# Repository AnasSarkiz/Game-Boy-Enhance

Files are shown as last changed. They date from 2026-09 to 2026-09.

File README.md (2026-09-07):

# S4 retro game console in tscircuit

The active project is now a **tabletop HDMI console with USB controllers**, using **T113-S4 / T113M4020DC0**. The default `index.circuit.tsx` opens the S4 design.

The connected draft has **103 components**, a **130 × 110 mm four-layer board**, and seven schematic sheets. It includes power, CPU/clocks/reset, storage/recovery, one protected USB controller port and four labelled indicators: **POWER, RUN, ERROR, USB FAULT**. All supplier footprints and courtyards remain unchanged. The green LED's reversed imported symbol labels are corrected against its manufacturer drawing.

**Routing is disabled. HDMI circuitry, power qualification and a tested firmware image remain incomplete. Do not fabricate.** Placement and connection audits pass; no copper-short DRC or hardware validation has been performed. Registry v1.0.3 remains the earlier draft; GitHub contains the newer console conversion.

See [console design and LED behaviour](s4/CONSOLE-REVIEW.md), [blockers](s4/BLOCKERS.md), [sourcing](s4/JLCPCB-PARTS.md), [current BOM](s4/reports/power-core-bom.csv), and [reproduction commands](s4/README.md).

The user-authorized console change replaces onboard game buttons with USB controllers and speaker/headphone/volume circuitry with TV audio. These are documented scope changes, not DNP workarounds. The previous [Nintendo adaptation](README-AGBM-02.md) and [analog audio review](s4/AUDIO-RETENTION-REVIEW.md) remain historical references.

The original [MouseBiteLabs Enhance](https://github.com/MouseBiteLabs/Game-Boy-Enhance) and pinned Trellis Core references retain their license/attribution notices. See [LICENSE.md](LICENSE.md).

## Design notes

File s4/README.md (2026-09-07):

# T113-S4 tabletop HDMI console

The user approved a tabletop console instead of a handheld. The active processor remains **T113M4020DC0 / C41411351**, using the authorized unchanged S3 supplier geometry. Exact S4 electrical/package qualification remains open.

The connected core has **103 components, 54 nets and seven schematic sheets** on a **130 × 110 mm four-layer board**. Power, CPU/clocks/reset, SD boot storage, USB-C power/recovery, one protected USB-A controller port and four status LEDs are present. HDMI video/audio, source-current management, debug access and a tested Linux/emulator image remain required. Routing stays disabled, with minimum vias of 0.45/0.30 mm.

| Indicator | Meaning |
|---|---|
| POWER, green | 3.3 V rail present |
| RUN, green | Firmware-driven Linux heartbeat |
| ERROR, red | Firmware-reported fault/panic when integrated |
| USB FAULT, red | Hardware USB power-switch fault |

See [connection details and sources](CONSOLE-REVIEW.md), [blockers](BLOCKERS.md), [supplier table](JLCPCB-PARTS.md) and [firmware integration fragment](firmware/console-leds.dtsi). None of the LEDs proves full-board health. The firmware fragment is not a bootable or tested image.

## Active checks

From the repository root, using the installed Bun/tsci toolchain:

```sh
bun run prepare:s4:console
bun run generate:s4:core
bun run typecheck
bun run audit:s4:imports
bun run check:s4:netlist
bun run check:s4:placement
bun run build:s4:core
bun run audit:s4:core
bun run audit:s4:console
bun run audit:s4:retention
bun run preview:s4:sheets
bun run check:release
```

The active stage checks pass with zero emitted diagnostics and a minimum courtyard gap of 0.1044 mm. `check:release` intentionally fails because required console circuitry and routed copper are absent. The separate upstream reference audit still reports unresolved source ERC findings; a successful export never means the reference was electrically qualified.

## Reference and history

The [Trellis Core reference](https://github.com/protolux-electronics/trellis_core/tree/db4fe71623c14bcea47d7457d0db4c99d3899124) supplies selected connections and parts; its custom KiCad footprints are not copied. Manufacturer documentation is reviewed separately. Local imports are genuine `tsci import --jlcpcb --use-exact-footprint` outputs, not handwritten footprints or a fabricated package.

The original AGB CPU/SRAM, LCD, cartridge/link interfaces, battery operation and handheld controls/audio are outside the new tabletop product scope. The [240-row historical disposition table](reports/enhance-retention.csv) records this change without DNP entries. `audio.json`, `controls.json`, audio-only scripts and their reports describe the previous handheld adaptation; they are not inputs to the active console generator or current acceptance checks.

Registry v1.0.3 remains the earlier 112-component stage. The current console entrypoint is available on GitHub; a future registry update must revise its explicit package boundary and release gate, then validate the packaged entrypoint.

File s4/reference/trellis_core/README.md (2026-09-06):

# Trellis Core

This repo serves as a minimum hardware design for the Allwinner T113-S4 (part
number sometimes referred to as T113M4020). This is pin-compatible with the
T113-S3, but with 256MB of RAM in-package. Although generally software-agnostic,
this repo is designed to be used with [Nerves](https://nerves-project.org) and
[nerves_system_trellis](https://github.com/protolux-electronics/nerves_system_trellis).

A screenshot of the PCB 3D rendering

> [!NOTE]
> This hardware design has been extracted out of several proven designs that I
> have previously ordered and tested. While the schematic should be sufficient
> to minimally bring up Linux on this board, the routing and layout as is
> available in this repo has not been tested. You will almost certainly need to
> change it for your application. See the suggestions below.

Want to view the schematic and layout in your browser? Paste this repo's URL
into [KiCanvas](https://kicanvas.org/) by
[@theacodes](https://github.com/theacodes).

## Features

- Allwinner T113-S4 processor
- Flash storage - up to 8GB
- USB-C (power and data)

## Getting Started

[KiCad](https://kicad.org) version 9 or later is required to modify these
designs. To get started, clone this repo and open `trellis_core.kicad_pro` (you
may rename all `trellis_core.kicad_*` files first, if desired). The schematic
already includes:

- DC/DC converters for 3.3V and 0.9V
- 24MHz and 32.768kHz crystals for clocks
- Decoupling capacitors, strapping resistors
- SD-compatible flash storage
- Reset and FEL mode buttons
- UART debug console (UART4)

To add your required peripherals, connect the appropriate signals in the
`CPU IO` sheet. You can see the GPIO pin multiplexing capabilities for the chip
on page 30 of the
[T113 datasheet](https://linux-sunxi.org/images/7/73/T113-s3_datasheet_v1.6.pdf)

## Routing Example

The routing shown in the example board was done rather quickly to showcase the
basics of routing a PCB, while also showing best practices. It uses pretty
standard and inexpensive processes - including 0.2mm minimum trace size, 0.3mm
via drill diameter, and 0402 components. Part numbers have been included in the
metadata for each component, and parts were chosen to maximize the use of basic
and preferred components with JLC assembly.

The board uses a standard 4-layer stackup, with the following layers:

| Layer  | Type |
| --- | --- |
| Top | Signal + GND |
| In1 | GND Plane |
| In2 | 3.3V Plane |
| Bottom | Signal + GND |

For the USB trace, 90 Ohm impedance is required. The trace width and spacing was
calculated for the JLC04161H-7628 stackup from JLCPCB, using the
[JLCPCB impedance calculator](https://jlcpcb.com/pcb-impedance-calculator).
Different manufacturers or stackups may require different settings - please
double check before ordering.

Finally, this design only populates components on the top side to reduce
assembly complexity and cost.

### Suggestions

As mentioned above, this exact design has not been ordered and tested
(derivatives have been, though). If you use this as the template for your
project, I suggest making the following changes to the routing:

- Use wider traces and vias for power connections: 0.9V, 1.5V, 1.8V.
- Any capacitor or resistor in the first row of components around the chip
  should stay close to the chip. Do not move them very far away, as they are
  required for the stability of the design
- If using double sided assembly, feel free to place the decoupling capacitors
  on the reverse side. This will simplify some of the routing and fanout of
  signals
- Keep the SDIO signals for the flash chip relatively short. Right now, they are
  between 20mm and 25mm in length. They should be approximately the same
  length - no more than 10mm different. SDIO is a relatively high speed signal
  of about 50MHz in this configuration. Trace length tuning has been used on
  some of the traces to meet this requirement (don't stress too much though -
  50MHz is pretty forgiving)
- Add stitching vias. Currently, the GND planes are not very well connected, as
  I did not place stitching vias. Via on traces for high speed signals should
  have a nearby GND via, and empty space could be filled with a grid via pattern

## License

Copyright 2025 by Protolux Electronics SARL-S

Trellis Core hardware design files are released under the CERN Open Hardware
Licence, Permissive (CERN-OHL-P). See the LICENSE file for the complete legal
text. In summary:

- You are free to use, study, modify, and distribute the design files for any
  purpose, including personal, educational, or commercial.
- You may make and sell products based on this design without any obligation to
  release your own modifications.
- If you do choose to share modified design files, you must:
  - Retain existing copyright and license notices.
  - Include a short note describing your modifications (what was changed and
    when).
  - Provide a copy of the CERN-OHL-P license alongside your files.

This is a permissive open hardware license, and is similar in spirit to MIT or
BSD licenses in software. It encourages reuse, even in commercial contexts,
while preserving proper attribution.

> [!NOTE]
> Some 3D component models and other assets in this repository are provided
> under their original authors’ licenses. Refer to the individual files or their
> directories for details.

Disclaimer: The Trellis Core design is provided "as is", without any warranty or
guarantee of performance. Use, manufacture, or modification of this hardware is
entirely at your own risk.

## Trademark and Logo Use

The Protolux Electronics name and logo are trademarks of Protolux Electronics
SARL-S.

These marks are not licensed under the CERN-OHL-P license. You may not use the
Protolux Electronics logo or trademarks on any modified versions of this
hardware, on derivative products, or in any way that suggests endorsement or
origin from Protolux Electronics, unless you have received prior written
permission.

## Projects Using this Design

Feel free to open a PR to add your project here! These are some existing
projects that are based off of this design:

| Name | Author | Description |
| --- | --- | --- |
| [Wisteria](https://github.com/protolux-electronics/wisteria_hardware) | Protolux Electronics/Gus Workman | Wisteria is the hardware for the 2025 Goatmire e-ink name badge. Read more about it [here](https://protolux.io/projects/goatmire2025) |
| [Trellis Dev Kit](https://github.com/protolux-electronics/trellis_hardware) | Protolux Electronics/Gus Workman | WIP! Check back soon :) |
| [Nerves Getting Started Hardware Kit]() | Protolux Electronics/Gus Workman | WIP! Check back soon :) |
| Your board here | You | Share your design - open a PR! |

## Designed by Protolux Electronics

Need help with your next embedded project? Interested in a customized T113-based
Nerves board? We're Protolux Electronics, a Luxembourg-based consultancy that
provides hardware and embedded software design services, as well as
manufacturing support. We specialize in embedded solutions using Nerves and
Elixir. Check us out at [https://protolux.io](https://protolux.io)

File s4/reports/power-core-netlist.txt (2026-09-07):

$ tsci check netlist s4/power-core.circuit.tsx
Errors: 0
Warnings: 0

Readable Netlist:
COMPONENTS:
 - C1: 10uF capacitor
 - C2: 10pF capacitor
 - C3: 10uF capacitor
 - C4: 10pF capacitor
 - C5: 22uF capacitor
 - C6: 22uF capacitor
 - C7: 10uF capacitor
 - C8: 100nF capacitor
 - R1: 100kΩ resistor
 - R2: 453kΩ resistor
 - R3: 100kΩ resistor
 - R5: 51kΩ resistor
 - R6: 100kΩ resistor
 - R7: 100kΩ resistor
 - U1: TLV62569PDDCR
 - U2: TLV62569PDDCR
 - L1: L1, source_component
 - L2: L2, source_component
 - C9: 2.2uF capacitor
 - C10: 10uF capacitor
 - C11: 100nF capacitor
 - C12: 100nF capacitor
 - C13: 100nF capacitor
 - C14: 100nF capacitor
 - C15: 100nF capacitor
 - C16: 2.2uF capacitor
 - C17: 100nF capacitor
 - C18: 100nF capacitor
 - C19: 100nF capacitor
 - C20: 100nF capacitor
 - C21: 100nF capacitor
 - C22: 10uF capacitor
 - C23: 100nF capacitor
 - C24: 100nF capacitor
 - C25: 100nF capacitor
 - C26: 100nF capacitor
 - C27: 100nF capacitor
 - C28: 2.2uF capacitor
 - C29: 10uF capacitor
 - C30: 100nF capacitor
 - C31: 100nF capacitor
 - C32: 10pF capacitor
 - C33: 10pF capacitor
 - C34: 100nF capacitor
 - C35: 100nF capacitor
 - C36: 18pF capacitor
 - C37: 18pF capacitor
 - C38: 100nF capacitor
 - C39: 100nF capacitor
 - C40: 2.2uF capacitor
 - R10: 240Ω resistor
 - R11: 100kΩ resistor
 - U3: T113M4020DC0
 - SW1: SW1, source_component
 - Y1: Y1, source_component
 - Y2: Y2, source_component
 - R12: 5.1kΩ resistor
 - R13: 5.1kΩ resistor
 - R14: 5.1kΩ resistor
 - R24: 5.1kΩ resistor
 - R25: 5.1kΩ resistor
 - R15: 5.1kΩ resistor
 - R16: 5.1kΩ resistor
 - U4: USBLC6-2SC6
 - F1: F1, source_component
 - J1: J1, source_component
 - C41: 10uF capacitor
 - C42: 100nF capacitor
 - C43: 100nF capacitor
 - C44: 100nF capacitor
 - R17: 51kΩ resistor
 - R18: 51kΩ resistor
 - R19: 51kΩ resistor
 - R20: 51kΩ resistor
 - R21: 51kΩ resistor
 - R22: 5.1kΩ resistor
 - R23: 22Ω resistor
 - U5: ZDSD04GLGEAG
 - U6: SN74AHC1G08DCKR
 - SW2: SW2, source_component
 - R4: 1kΩ resistor
 - D1: D1, source_component
 - LED2: LED2, source_component
 - LED3: LED3, source_component
 - LED4: LED4, source_component
 - Q2: Q2, source_component
 - Q3: Q3, source_component
 - R48: 1kΩ resistor
 - R49: 1kΩ resistor
 - R50: 1kΩ resistor
 - R51: 10kΩ resistor
 - R52: 100kΩ resistor
 - R53: 10kΩ resistor
 - R54: 100kΩ resistor
 - U9: TPS2051BDBVR
 - U10: USBLC6-2SC6
 - J4: J4, source_component
 - R55: 100kΩ resistor
 - R56: 10kΩ resistor
 - C70: 100nF capacitor
 - C71: 10uF capacitor
 - C72: 220uF capacitor
 - C73: 100nF capacitor

NET: VDD_CORE_0V9
  - U3 VDD_SYS2
  - U3 VDD_SYS1
  - U3 VDD_SYS0
  - U3 VDD_CORE1
  - U3 VDD_CORE0
  - R5 pin1
  - L2 pin2 (-)
  - C6 pin1 (+)
  - C5 pin1 (+)
  - C4 pin1 (+)
  - C27 pin1 (+)
  - C26 pin1 (+)
  - C25 pin1 (+)
  - C24 pin1 (+)
  - C23 pin1 (+)
  - C22 pin1 (+)

NET: DDR_1V5
  - U3 VCC_DRAM1
  - U3 VCC_DRAM0
  - U3 LDOB_OUT
  - C31 pin1 (+)
  - C30 pin1 (+)
  - C29 pin1 (+)
  - C28 pin1 (+)

NET: LDOA_1V8
  - R11 pin1
  - U3 HPVCC
  - U3 AVCC
  - U3 VCC_LVDS
  - U3 VDD18_DRAM
  - U3 LDOA_OUT
  - U3 VCC_RTC
  - U3 VCC_PLL
  - U3 VCC_TVIN
  - C35 pin1 (+)
  - C34 pin1 (+)
  - C21 pin1 (+)
  - C20 pin1 (+)
  - C19 pin1 (+)
  - C18 pin1 (+)
  - C17 pin1 (+)
  - C16 pin1 (+)

NET: SYS_3V3
  - R56 pin1
  - LED4 anode (+)
  - LED3 anode (+)
  - LED2 anode (+)
  - U6 VCC
  - U5 VDD
  - U3 VCC_IO
  - U3 VCC_TVOUT
  - U3 VCC_PD
  - U3 VCC_PE
  - U3 LDO_IN
  - U3 VCC_PG
  - R22 pin2
  - R21 pin1
  - R20 pin1
  - R2 pin1
  - R19 pin1
  - R18 pin1
  - R17 pin1
  - R13 pin1
  - R12 pin1
  - L1 pin2 (-)
  - D1 anode (+)
  - C9 pin1 (+)
  - C43 pin1 (+)
  - C42 pin1 (+)
  - C41 pin1 (+)
  - C3 pin1 (+)
  - C2 pin1 (+)
  - C15 pin1 (+)
  - C14 pin1 (+)
  - C13 pin1 (+)
  - C12 pin1 (+)
  - C11 pin1 (+)
  - C10 pin1 (+)

NET: DXIN
  - Y1 pin1
  - U3 DXIN
  - C32 pin1 (+)

NET: DXOUT
  - Y1 pin3
  - U3 DXOUT
  - C33 pin1 (+)

NET: LXIN
  - Y2 pin1 (+)
  - U3 X32KIN
  - C36 pin1 (+)

NET: LXOUT
  - Y2 pin2 (-)
  - U3 X32KOUT
  - C37 pin1 (+)

NET: RESET_N
  - U3 RESET
  - SW1 pin2
  - R11 pin2
  - C40 pin1 (+)

NET: BOARD_ID_1
  - U3 PF6
  - R14 pin1

NET: BOARD_ID_2
  - U3 PE8
  - R24 pin1

NET: BOARD_ID_3
  - U3 PE9
  - R25 pin1

NET: BOOT_SEL0
  - U3 PC4
  - R13 pin2

NET: BOOT_SEL1
  - U3 PC5
  - R12 pin2

NET: SDC0_CLK
  - U6 A
  - U3 PF2

NET: SDC0_CMD
  - U5 CMD
  - U3 PF3
  - R19 pin2

NET: SDC0_D0
  - U5 DAT0
  - U3 PF1
  - R18 pin2

NET: SDC0_D1
  - U5 DAT1
  - U3 PF0
  - R17 pin2

NET: SDC0_D2
  - U5 DAT2
  - U3 PF5
  - R21 pin2

NET: SDC0_D3
  - U5 DAT3
  - U3 PF4
  - R20 pin2

NET: SYS_3V3_PG
  - U2 EN
  - U1 PG
  - R6 pin2
  - C8 pin1 (+)

NET: USB0_CC1
  - R15 pin1
  - J1 A5

NET: USB0_CC2
  - R16 pin1
  - J1 B5

NET: USB0_DM
  - J1 B7
  - J1 A7
  - U4 IO11
  - U4 IO12
  - U3 USB0_DM

NET: USB0_DP
  - J1 A6
  - J1 B6
  - U4 IO21
  - U4 IO22
  - U3 USB0_DP

NET: GND
  - C73 pin2 (-)
  - C72 pin2 (-)
  - C71 pin2 (-)
  - C70 pin2 (-)
  - R55 pin2
  - J4 SH2
  - J4 SH1
  - J4 GND
  - U10 GND
  - U9 GND
  - R54 pin2
  - R52 pin2
  - Q3 pin2
  - Q2 pin2
  - Y1 pin4
  - Y1 pin2
  - U6 GND
  - U5 GND
  - U4 GND
  - U3 FMINL
  - U3 FMINR
  - U3 AGND
  - U3 EPAD
  - U2 GND
  - U1 GND
  - SW2 pin1
  - SW1 pin1
  - R7 pin2
  - R4 pin2
  - R3 pin2
  - R25 pin2
  - R24 pin2
  - R16 pin2
  - R15 pin2
  - R14 pin2
  - R10 pin2
  - J1 B1A12
  - J1 A1B12
  - J1 pin4
  - J1 pin3
  - J1 pin2
  - J1 pin1
  - C9 pin2 (-)
  - C8 pin2 (-)
  - C7 pin2 (-)
  - C6 pin2 (-)
  - C5 pin2 (-)
  - C44 pin2 (-)
  - C43 pin2 (-)
  - C42 pin2 (-)
  - C41 pin2 (-)
  - C40 pin2 (-)
  - C39 pin2 (-)
  - C38 pin2 (-)
  - C37 pin2 (-)
  - C36 pin2 (-)
  - C35 pin2 (-)
  - C34 pin2 (-)
  - C33 pin2 (-)
  - C32 pin2 (-)
  - C31 pin2 (-)
  - C30 pin2 (-)
  - C3 pin2 (-)
  - C29 pin2 (-)
  - C28 pin2 (-)
  - C27 pin2 (-)
  - C26 pin2 (-)
  - C25 pin2 (-)
  - C24 pin2 (-)
  - C23 pin2 (-)
  - C22 pin2 (-)
  - C21 pin2 (-)
  - C20 pin2 (-)
  - C19 pin2 (-)
  - C18 pin2 (-)
  - C17 pin2 (-)
  - C16 pin2 (-)
  - C15 pin2 (-)
  - C14 pin2 (-)
  - C13 pin2 (-)
  - C12 pin2 (-)
  - C11 pin2 (-)
  - C10 pin2 (-)
  - C1 pin2 (-)

NET: FEL_CLOCK_ENABLE
  - U6 B
  - SW2 pin2
  - R22 pin1
  - C44 pin1 (+)

NET: Net__D1_K_
  - R4 pin1
  - D1 cathode (-)

NET: SDC0_CLK_BUFFERED
  - U6 Y
  - R23 pin1

NET: BUCK_3V3_EN
  - U1 EN
  - R1 pin2

NET: BUCK_3V3_FB
  - U1 FB
  - R3 pin1
  - R2 pin2
  - C2 pin2 (-)

NET: BUCK_3V3_SW
  - U1 SW
  - L1 pin1 (+)

NET: BUCK_CORE_FB
  - U2 FB
  - R7 pin1
  - R5 pin2
  - C4 pin2 (-)

NET: BUCK_CORE_SW
  - U2 SW
  - L2 pin1 (+)

NET: DDR_ZQ
  - U3 DZQ
  - R10 pin1

NET: Net__U3F_VRA1_
  - U3 VRA1
  - C39 pin1 (+)

NET: Net__U3F_VRA2_
  - U3 VRA2
  - C38 pin1 (+)

NET: USB_C_VBUS_5V
  - U4 VBUS
  - J1 B4A9
  - J1 A4B9
  - F1 pin1

NET: SDC0_CLK_STORAGE
  - U5 CLK
  - R23 pin2

NET: INPUT_5V
  - C71 pin1 (+)
  - C70 pin1 (+)
  - U9 IN
  - U2 VIN
  - U1 VIN
  - R6 pin1
  - R1 pin1
  - F1 pin2
  - C7 pin1 (+)
  - C1 pin1 (+)

NET: LED_RUN
  - R51 pin1
  - U3 PE0

NET: LED_RUN_BASE
  - R52 pin1
  - Q2 pin1
  - R51 pin2

NET: LED_RUN_CATHODE
  - R48 pin1
  - LED2 cathode (-)

NET: LED_RUN_SINK
  - Q2 pin3
  - R48 pin2

NET: LED_ERROR
  - R53 pin1
  - U3 PE1

NET: LED_ERROR_BASE
  - R54 pin1
  - Q3 pin1
  - R53 pin2

NET: LED_ERROR_CATHODE
  - R49 pin1
  - LED3 cathode (-)

NET: LED_ERROR_SINK
  - Q3 pin3
  - R49 pin2

NET: LED_USB_FAULT_CATHODE
  - R50 pin1
  - LED4 cathode (-)

NET: USB_HOST_FAULT_N
  - R50 pin2
  - R56 pin2
  - U3 PG9
  - U9 N_OC

NET: USB_HOST_ENABLE
  - R55 pin1
  - U3 PG10
  - U9 EN

NET: USB_HOST_5V
  - C73 pin1 (+)
  - C72 pin1 (+)
  - U10 VBUS
  - J4 VCC
  - U9 OUT

NET: USB1_DM
  - J4 D_NEG
  - U10 IO11
  - U10 IO12
  - U3 USB1_DM

NET: USB1_DP
  - J4 D_POS
  - U10 IO21
  - U10 IO22
  - U3 USB1_DP

COMPONENT_PINS:
C1 (10uF undefined)
- pin1(pos): NETS(INPUT_5V)
- pin2(neg): NETS(GND)

C2 (10pF undefined)
- pin1(pos): NETS(SYS_3V3)
- pin2(neg): NETS(BUCK_3V3_FB)

C3 (10uF undefined)
- pin1(pos): NETS(SYS_3V3)
- pin2(neg): NETS(GND)

C4 (10pF undefined)
- pin1(pos): NETS(VDD_CORE_0V9)
- pin2(neg): NETS(BUCK_CORE_FB)

C5 (22uF undefined)
- pin1(pos): NETS(VDD_CORE_0V9)
- pin2(neg): NETS(GND)

C6 (22uF undefined)
- pin1(pos): NETS(VDD_CORE_0V9)
- pin2(neg): NETS(GND)

C7 (10uF undefined)
- pin1(pos): NETS(INPUT_5V)
- pin2(neg): NETS(GND)

C8 (100nF undefined)
- pin1(pos): NETS(SYS_3V3_PG)
- pin2(neg): NETS(GND)

R1 (100kΩ undefined)
- pin1(anode, pos, left): NETS(INPUT_5V)
- pin2(cathode, neg, right): NETS(BUCK_3V3_EN)

R2 (453kΩ undefined)
- pin1(anode, pos, left): NETS(SYS_3V3)
- pin2(cathode, neg, right): NETS(BUCK_3V3_FB)

R3 (100kΩ undefined)
- pin1(anode, pos, left): NETS(BUCK_3V3_FB)
- pin2(cathode, neg, right): NETS(GND)

R5 (51kΩ undefined)
- pin1(anode, pos, left): NETS(VDD_CORE_0V9)
- pin2(cathode, neg, right): NETS(BUCK_CORE_FB)

R6 (100kΩ undefined)
- pin1(anode, pos, left): NETS(INPUT_5V)
- pin2(cathode, neg, right): NETS(SYS_3V3_PG)

R7 (100kΩ undefined)
- pin1(anode, pos, left): NETS(BUCK_CORE_FB)
- pin2(cathode, neg, right): NETS(GND)

U1 (TLV62569PDDCR)
- pin1(EN): NETS(BUCK_3V3_EN)
- pin2(GND): NETS(GND)
- pin3(SW): NETS(BUCK_3V3_SW)
- pin4(VIN): NETS(INPUT_5V)
- pin5(PG): NETS(SYS_3V3_PG)
- pin6(FB): NETS(BUCK_3V3_FB)

U2 (TLV62569PDDCR)
- pin1(EN): NETS(SYS_3V3_PG)
- pin2(GND): NETS(GND)
- pin3(SW): NETS(BUCK_CORE_SW)
- pin4(VIN): NETS(INPUT_5V)
- pin5(PG): NOT_CONNECTED
- pin6(FB): NETS(BUCK_CORE_FB)

L1 (XRIM252012S2R2MBCA)
- pin1(anode, pos, left): NETS(BUCK_3V3_SW)
- pin2(cathode, neg, right): NETS(SYS_3V3)

L2 (XRIM252012S2R2MBCA)
- pin1(anode, pos, left): NETS(BUCK_CORE_SW)
- pin2(cathode, neg, right): NETS(VDD_CORE_0V9)

C9 (2.2uF undefined)
- pin1(pos): NETS(SYS_3V3)
- pin2(neg): NETS(GND)

C10 (10uF undefined)
- pin1(pos): NETS(SYS_3V3)
- pin2(neg): NETS(GND)

C11 (100nF undefined)
- pin1(pos): NETS(SYS_3V3)
- pin2(neg): NETS(GND)

C12 (100nF undefined)
- pin1(pos): NETS(SYS_3V3)
- pin2(neg): NETS(GND)

C13 (100nF undefined)
- pin1(pos): NETS(SYS_3V3)
- pin2(neg): NETS(GND)

C14 (100nF undefined)
- pin1(pos): NETS(SYS_3V3)
- pin2(neg): NETS(GND)

C15 (100nF undefined)
- pin1(pos): NETS(SYS_3V3)
- pin2(neg): NETS(GND)

C16 (2.2uF undefined)
- pin1(pos): NETS(LDOA_1V8)
- pin2(neg): NETS(GND)

C17 (100nF undefined)
- pin1(pos): NETS(LDOA_1V8)
- pin2(neg): NETS(GND)

C18 (100nF undefined)
- pin1(pos): NETS(LDOA_1V8)
- pin2(neg): NETS(GND)

C19 (100nF undefined)
- pin1(pos): NETS(LDOA_1V8)
- pin2(neg): NETS(GND)

C20 (100nF undefined)
- pin1(pos): NETS(LDOA_1V8)
- pin2(neg): NETS(GND)

C21 (100nF undefined)
- pin1(pos): NETS(LDOA_1V8)
- pin2(neg): NETS(GND)

C22 (10uF undefined)
- pin1(pos): NETS(VDD_CORE_0V9)
- pin2(neg): NETS(GND)

C23 (100nF undefined)
- pin1(pos): NETS(VDD_CORE_0V9)
- pin2(neg): NETS(GND)

C24 (100nF undefined)
- pin1(pos): NETS(VDD_CORE_0V9)
- pin2(neg): NETS(GND)

C25 (100nF undefined)
- pin1(pos): NETS(VDD_CORE_0V9)
- pin2(neg): NETS(GND)

C26 (100nF undefined)
- pin1(pos): NETS(VDD_CORE_0V9)
- pin2(neg): NETS(GND)

C27 (100nF undefined)
- pin1(pos): NETS(VDD_CORE_0V9)
- pin2(neg): NETS(GND)

C28 (2.2uF undefined)
- pin1(pos): NETS(DDR_1V5)
- pin2(neg): NETS(GND)

C29 (10uF undefined)
- pin1(pos): NETS(DDR_1V5)
- pin2(neg): NETS(GND)

C30 (100nF undefined)
- pin1(pos): NETS(DDR_1V5)
- pin2(neg): NETS(GND)

C31 (100nF undefined)
- pin1(pos): NETS(DDR_1V5)
- pin2(neg): NETS(GND)

C32 (10pF undefined)
- pin1(pos): NETS(DXIN)
- pin2(neg): NETS(GND)

C33 (10pF undefined)
- pin1(pos): NETS(DXOUT)
- pin2(neg): NETS(GND)

C34 (100nF undefined)
- pin1(pos): NETS(LDOA_1V8)
- pin2(neg): NETS(GND)

C35 (100nF undefined)
- pin1(pos): NETS(LDOA_1V8)
- pin2(neg): NETS(GND)

C36 (18pF undefined)
- pin1(pos): NETS(LXIN)
- pin2(neg): NETS(GND)

C37 (18pF undefined)
- pin1(pos): NETS(LXOUT)
- pin2(neg): NETS(GND)

C38 (100nF undefined)
- pin1(pos): NETS(Net__U3F_VRA2_)
- pin2(neg): NETS(GND)

C39 (100nF undefined)
- pin1(pos): NETS(Net__U3F_VRA1_)
- pin2(neg): NETS(GND)

C40 (2.2uF undefined)
- pin1(pos): NETS(RESET_N)
- pin2(neg): NETS(GND)

R10 (240Ω undefined)
- pin1(anode, pos, left): NETS(DDR_ZQ)
- pin2(cathode, neg, right): NETS(GND)

R11 (100kΩ undefined)
- pin1(anode, pos, left): NETS(LDOA_1V8)
- pin2(cathode, neg, right): NETS(RESET_N)

U3 (T113M4020DC0)
- pin1(PG6): NOT_CONNECTED
- pin2(PG7): NOT_CONNECTED
- pin3(PG8): NOT_CONNECTED
- pin4(PG9): NETS(USB_HOST_FAULT_N)
- pin5(PG10): NETS(USB_HOST_ENABLE)
- pin6(PG11): NOT_CONNECTED
- pin7(PF0): NETS(SDC0_D1)
- pin8(PF1): NETS(SDC0_D0)
- pin9(PF2): NETS(SDC0_CLK)
- pin10(PF3): NETS(SDC0_CMD)
- pin11(PF4): NETS(SDC0_D3)
- pin12(PF5): NETS(SDC0_D2)
- pin13(PF6): NETS(BOARD_ID_1)
- pin14(PC7): NOT_CONNECTED
- pin15(PC6): NOT_CONNECTED
- pin16(PC5): NETS(BOOT_SEL1)
- pin17(PC4): NETS(BOOT_SEL0)
- pin18(PC3): NOT_CONNECTED
- pin19(PC2): NOT_CONNECTED
- pin20(VCC_PLL): NETS(LDOA_1V8)
- pin21(REFCLK_OUT): NOT_CONNECTED
- pin22(DXOUT): NETS(DXOUT)
- pin23(DXIN): NETS(DXIN)
- pin24(X32KOUT): NETS(LXOUT)
- pin25(X32KIN): NETS(LXIN)
- pin26(VCC_RTC): NETS(LDOA_1V8)
- pin27(RESET): NETS(RESET_N)
- pin28(LDOA_OUT): NETS(LDOA_1V8)
- pin29(LDO_IN): NETS(SYS_3V3)
- pin30(LDOB_OUT): NETS(DDR_1V5)
- pin31(PE13): NOT_CONNECTED
- pin32(PE12): NOT_CONNECTED
- pin33(PE3): NOT_CONNECTED
- pin34(VCC_PE): NETS(SYS_3V3)
- pin35(PE2): NOT_CONNECTED
- pin36(PE11): NOT_CONNECTED
- pin37(PE10): NOT_CONNECTED
- pin38(PE9): NETS(BOARD_ID_3)
- pin39(PE8): NETS(BOARD_ID_2)
- pin40(PE7): NOT_CONNECTED
- pin41(PE6): NOT_CONNECTED
- pin42(PE5): NOT_CONNECTED
- pin43(PE4): NOT_CONNECTED
- pin44(PE0): NETS(LED_RUN)
- pin45(PE1): NETS(LED_ERROR)
- pin46(VDD_SYS0): NETS(VDD_CORE_0V9)
- pin47(DZQ): NETS(DDR_ZQ)
- pin48(VCC_DRAM0): NETS(DDR_1V5)
- pin49(VCC_DRAM1): NETS(DDR_1V5)
- pin50(VDD18_DRAM): NETS(LDOA_1V8)
- pin51(VDD_SYS1): NETS(VDD_CORE_0V9)
- pin52(PD22): NOT_CONNECTED
- pin53(PD21): NOT_CONNECTED
- pin54(PD20): NOT_CONNECTED
- pin55(PD0): NOT_CONNECTED
- pin56(PD1): NOT_CONNECTED
- pin57(PD2): NOT_CONNECTED
- pin58(PD3): NOT_CONNECTED
- pin59(PD4): NOT_CONNECTED
- pin60(PD5): NOT_CONNECTED
- pin61(PD6): NOT_CONNECTED
- pin62(PD7): NOT_CONNECTED
- pin63(PD8): NOT_CONNECTED
- pin64(PD9): NOT_CONNECTED
- pin65(VCC_LVDS): NETS(LDOA_1V8)
- pin66(VCC_PD): NETS(SYS_3V3)
- pin67(PD10): NOT_CONNECTED
- pin68(PD11): NOT_CONNECTED
- pin69(PD13): NOT_CONNECTED
- pin70(PD12): NOT_CONNECTED
- pin71(PD14): NOT_CONNECTED
- pin72(PD15): NOT_CONNECTED
- pin73(PD16): NOT_CONNECTED
- pin74(PD17): NOT_CONNECTED
- pin75(PD18): NOT_CONNECTED
- pin76(PD19): NOT_CONNECTED
- pin77(VCC_TVOUT): NETS(SYS_3V3)
- pin78(TVOUT0): NOT_CONNECTED
- pin79(PB7): NOT_CONNECTED
- pin80(PB6): NOT_CONNECTED
- pin81(VDD_SYS2): NETS(VDD_CORE_0V9)
- pin82(PB5): NOT_CONNECTED
- pin83(VCC_IO): NETS(SYS_3V3)
- pin84(PB4): NOT_CONNECTED
- pin85(PB3): NOT_CONNECTED
- pin86(PB2): NOT_CONNECTED
- pin87(MICIN3P): NOT_CONNECTED
- pin88(MICIN3N): NOT_CONNECTED
- pin89(AVCC): NETS(LDOA_1V8)
- pin90(VRA2): NETS(Net__U3F_VRA2_)
- pin91(AGND): NETS(GND)
- pin92(VRA1): NETS(Net__U3F_VRA1_)
- pin93(FMINR): NETS(GND)
- pin94(FMINL): NETS(GND)
- pin95(LINEINR): NOT_CONNECTED
- pin96(LINEINL): NOT_CONNECTED
- pin97(HPVCC): NETS(LDOA_1V8)
- pin98(HPOUTR): NOT_CONNECTED
- pin99(HPOUTL): NOT_CONNECTED
- pin100(HPOUTFB): NOT_CONNECTED
- pin101(GPADC0): NOT_CONNECTED
- pin102(TP_X1): NOT_CONNECTED
- pin103(TP_X2): NOT_CONNECTED
- pin104(TP_Y1): NOT_CONNECTED
- pin105(TP_Y2): NOT_CONNECTED
- pin106(NC0): NOT_CONNECTED
- pin107(VCC_TVIN): NETS(LDOA_1V8)
- pin108(TVIN0): NOT_CONNECTED
- pin109(TVIN1): NOT_CONNECTED
- pin110(TVIN_VRP): NOT_CONNECTED
- pin111(TVIN_VRN): NOT_CONNECTED
- pin112(USB1_DP): NETS(USB1_DP)
- pin113(USB1_DM): NETS(USB1_DM)
- pin114(USB0_DM): NETS(USB0_DM)
- pin115(USB0_DP): NETS(USB0_DP)
- pin116(VDD_CORE0): NETS(VDD_CORE_0V9)
- pin117(VDD_CORE1): NETS(VDD_CORE_0V9)
- pin118(PG1): NOT_CONNECTED
- pin119(PG2): NOT_CONNECTED
- pin120(PG0): NOT_CONNECTED
- pin121(PG3): NOT_CONNECTED
- pin122(PG5): NOT_CONNECTED
- pin123(PG4): NOT_CONNECTED
- pin124(PG12): NOT_CONNECTED
- pin125(PG13): NOT_CONNECTED
- pin126(PG14): NOT_CONNECTED
- pin127(PG15): NOT_CONNECTED
- pin128(VCC_PG): NETS(SYS_3V3)
- pin129(EPAD): NETS(GND)

SW1 (TSA010A2026B)
- pin1: NETS(GND)
- pin2: NETS(RESET_N)

Y1 (CM4024M00008001)
- pin1(left1, X1): NETS(DXIN)
- pin2(gnd2, top1, gnd1): NETS(GND)
- pin3(right1, X2): NETS(DXOUT)
- pin4(gnd1, bottom1, gnd2): NETS(GND)

Y2 (Q13FC13500004)
- pin1(pos, left, X1): NETS(LXIN)
- pin2(neg, right, X2): NETS(LXOUT)

R12 (5.1kΩ undefined)
- pin1(anode, pos, left): NETS(SYS_3V3)
- pin2(cathode, neg, right): NETS(BOOT_SEL1)

R13 (5.1kΩ undefined)
- pin1(anode, pos, left): NETS(SYS_3V3)
- pin2(cathode, neg, right): NETS(BOOT_SEL0)

R14 (5.1kΩ undefined)
- pin1(anode, pos, left): NETS(BOARD_ID_1)
- pin2(cathode, neg, right): NETS(GND)

R24 (5.1kΩ undefined)
- pin1(anode, pos, left): NETS(BOARD_ID_2)
- pin2(cathode, neg, right): NETS(GND)

R25 (5.1kΩ undefined)
- pin1(anode, pos, left): NETS(BOARD_ID_3)
- pin2(cathode, neg, right): NETS(GND)

R15 (5.1kΩ undefined)
- pin1(anode, pos, left): NETS(USB0_CC1)
- pin2(cathode, neg, right): NETS(GND)

R16 (5.1kΩ undefined)
- pin1(anode, pos, left): NETS(USB0_CC2)
- pin2(cathode, neg, right): NETS(GND)

U4 (USBLC6-2SC6)
- pin1(IO11): NETS(USB0_DM)
- pin2(GND): NETS(GND)
- pin3(IO21): NETS(USB0_DP)
- pin4(IO22): NETS(USB0_DP)
- pin5(VBUS): NETS(USB_C_VBUS_5V)
- pin6(IO12): NETS(USB0_DM)

F1 (JK-nSMD100-16)
- pin1: NETS(USB_C_VBUS_5V)
- pin2: NETS(INPUT_5V)

J1 (HX TYPE-C 16P L8.35)
- pin1: NETS(GND)
- pin2: NETS(GND)
- pin3: NETS(GND)
- pin4: NETS(GND)
- pin5(A1B12, GND1): NETS(GND)
- pin6(A4B9, VBUS1): NETS(USB_C_VBUS_5V)
- pin7(B1A12, GND2): NETS(GND)
- pin8(B4A9, VBUS2): NETS(USB_C_VBUS_5V)
- pin9(B5, CC2): NETS(USB0_CC2)
- pin10(A8, SBU1): NOT_CONNECTED
- pin11(B6, DP2): NETS(USB0_DP)
- pin12(A7, DN1): NETS(USB0_DM)
- pin13(A6, DP1): NETS(USB0_DP)
- pin14(B7, DN2): NETS(USB0_DM)
- pin15(A5, CC1): NETS(USB0_CC1)
- pin16(B8, SBU2): NOT_CONNECTED

C41 (10uF undefined)
- pin1(pos): NETS(SYS_3V3)
- pin2(neg): NETS(GND)

C42 (100nF undefined)
- pin1(pos): NETS(SYS_3V3)
- pin2(neg): NETS(GND)

C43 (100nF undefined)
- pin1(pos): NETS(SYS_3V3)
- pin2(neg): NETS(GND)

C44 (100nF undefined)
- pin1(pos): NETS(FEL_CLOCK_ENABLE)
- pin2(neg): NETS(GND)

R17 (51kΩ undefined)
- pin1(anode, pos, left): NETS(SYS_3V3)
- pin2(cathode, neg, right): NETS(SDC0_D1)

R18 (51kΩ undefined)
- pin1(anode, pos, left): NETS(SYS_3V3)
- pin2(cathode, neg, right): NETS(SDC0_D0)

R19 (51kΩ undefined)
- pin1(anode, pos, left): NETS(SYS_3V3)
- pin2(cathode, neg, right): NETS(SDC0_CMD)

R20 (51kΩ undefined)
- pin1(anode, pos, left): NETS(SYS_3V3)
- pin2(cathode, neg, right): NETS(SDC0_D3)

R21 (51kΩ undefined)
- pin1(anode, pos, left): NETS(SYS_3V3)
- pin2(cathode, neg, right): NETS(SDC0_D2)

R22 (5.1kΩ undefined)
- pin1(anode, pos, left): NETS(FEL_CLOCK_ENABLE)
- pin2(cathode, neg, right): NETS(SYS_3V3)

R23 (22Ω undefined)
- pin1(anode, pos, left): NETS(SDC0_CLK_BUFFERED)
- pin2(cathode, neg, right): NETS(SDC0_CLK_STORAGE)

U5 (ZDSD04GLGEAG)
- pin1(DAT2): NETS(SDC0_D2)
- pin2(DAT3): NETS(SDC0_D3)
- pin3(CLK): NETS(SDC0_CLK_STORAGE)
- pin4(GND): NETS(GND)
- pin5(CMD): NETS(SDC0_CMD)
- pin6(DAT0): NETS(SDC0_D0)
- pin7(DAT1): NETS(SDC0_D1)
- pin8(VDD): NETS(SYS_3V3)

U6 (SN74AHC1G08DCKR)
- pin1(A): NETS(SDC0_CLK)
- pin2(B): NETS(FEL_CLOCK_ENABLE)
- pin3(GND): NETS(GND)
- pin4(Y): NETS(SDC0_CLK_BUFFERED)
- pin5(VCC): NETS(SYS_3V3)

SW2 (TSA010A2026B)
- pin1: NETS(GND)
- pin2: NETS(FEL_CLOCK_ENABLE)

R4 (1kΩ undefined)
- pin1(anode, pos, left): NETS(Net__D1_K_)
- pin2(cathode, neg, right): NETS(GND)

D1 (19-21SYGC/S530-E2/4T)
- pin1(anode, pos): NETS(SYS_3V3)
- pin2(cathode, neg): NETS(Net__D1_K_)

LED2 (19-21SYGC/S530-E2/4T)
- pin1(anode, pos): NETS(SYS_3V3)
- pin2(cathode, neg): NETS(LED_RUN_CATHODE)

LED3 (19-217/R6C-AL1M2VY/6T)
- pin1(anode, pos): NETS(SYS_3V3)
- pin2(cathode, neg): NETS(LED_ERROR_CATHODE)

LED4 (19-217/R6C-AL1M2VY/6T)
- pin1(anode, pos): NETS(SYS_3V3)
- pin2(cathode, neg): NETS(LED_USB_FAULT_CATHODE)

Q2 (MMBT3904LT1G)
- pin1: NETS(LED_RUN_BASE)
- pin2: NETS(GND)
- pin3: NETS(LED_RUN_SINK)

Q3 (MMBT3904LT1G)
- pin1: NETS(LED_ERROR_BASE)
- pin2: NETS(GND)
- pin3: NETS(LED_ERROR_SINK)

R48 (1kΩ undefined)
- pin1(anode, pos, left): NETS(LED_RUN_CATHODE)
- pin2(cathode, neg, right): NETS(LED_RUN_SINK)

R49 (1kΩ undefined)
- pin1(anode, pos, left): NETS(LED_ERROR_CATHODE)
- pin2(cathode, neg, right): NETS(LED_ERROR_SINK)

R50 (1kΩ undefined)
- pin1(anode, pos, left): NETS(LED_USB_FAULT_CATHODE)
- pin2(cathode, neg, right): NETS(USB_HOST_FAULT_N)

R51 (10kΩ undefined)
- pin1(anode, pos, left): NETS(LED_RUN)
- pin2(cathode, neg, right): NETS(LED_RUN_BASE)

R52 (100kΩ undefined)
- pin1(anode, pos, left): NETS(LED_RUN_BASE)
- pin2(cathode, neg, right): NETS(GND)

R53 (10kΩ undefined)
- pin1(anode, pos, left): NETS(LED_ERROR)
- pin2(cathode, neg, right): NETS(LED_ERROR_BASE)

R54 (100kΩ undefined)
- pin1(anode, pos, left): NETS(LED_ERROR_BASE)
- pin2(cathode, neg, right): NETS(GND)

U9 (TPS2051BDBVR)
- pin1(OUT): NETS(USB_HOST_5V)
- pin2(GND): NETS(GND)
- pin3(N_OC): NETS(USB_HOST_FAULT_N)
- pin4(EN): NETS(USB_HOST_ENABLE)
- pin5(IN): NETS(INPUT_5V)

U10 (USBLC6-2SC6)
- pin1(IO11): NETS(USB1_DM)
- pin2(GND): NETS(GND)
- pin3(IO21): NETS(USB1_DP)
- pin4(IO22): NETS(USB1_DP)
- pin5(VBUS): NETS(USB_HOST_5V)
- pin6(IO12): NETS(USB1_DM)

J4 (902-131A1011D10100)
- pin1(VCC): NETS(USB_HOST_5V)
- pin2(D_NEG): NETS(USB1_DM)
- pin3(D_POS): NETS(USB1_DP)
- pin4(GND): NETS(GND)
- pin5(SH1): NETS(GND)
- pin6(SH2): NETS(GND)

R55 (100kΩ undefined)
- pin1(anode, pos, left): NETS(USB_HOST_ENABLE)
- pin2(cathode, neg, right): NETS(GND)

R56 (10kΩ undefined)
- pin1(anode, pos, left): NETS(SYS_3V3)
- pin2(cathode, neg, right): NETS(USB_HOST_FAULT_N)

C70 (100nF undefined)
- pin1(pos): NETS(INPUT_5V)
- pin2(neg): NETS(GND)

C71 (10uF undefined)
- pin1(pos): NETS(INPUT_5V)
- pin2(neg): NETS(GND)

C72 (220uF undefined)
- pin1(pos): NETS(USB_HOST_5V)
- pin2(neg): NETS(GND)

C73 (100nF undefined)
- pin1(pos): NETS(USB_HOST_5V)
- pin2(neg): NETS(GND)

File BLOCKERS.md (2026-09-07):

# Blockers and deviations

## Active tabletop console

The user approved an HDMI console with USB controllers. The active 103-component core adds POWER/RUN/ERROR/USB FAULT indicators and a protected host port; its placement/connection checks pass. HDMI, input-power qualification, S4 documentation, firmware, routing and prototype validation remain unfinished. See [current blockers](s4/BLOCKERS.md), [console review](s4/CONSOLE-REVIEW.md), and [parts table](s4/JLCPCB-PARTS.md).

The following notes describe the historical `agbm-02.circuit.tsx` design.

**Placement-stage work in progress, 2026-09-05. Routing is disabled. Do not fabricate this revision.**

## Sourcing

The [JLCPCB blocker table](JLCPCB-BLOCKERS.md) distinguishes missing exact matches, available alternatives, and catalog import failures.

The [assembly requirements](docs/ASSEMBLY-REQUIREMENTS.md) require every intended function to remain populated and operational. No DNP workaround is permitted. The unresolved CPU/ports, unqualified screen assembly and ineffective legacy JP3 are completion blockers even though no component is marked DNP.

1. **U1 Nintendo AGB CPU:** no verified JLCPCB listing for the original processor. A different TI MCU would not run this hardware as wired. The user's requirements to retain this CPU, import it from JLCPCB and avoid custom footprints cannot all be satisfied without a real catalog listing. All 128 real schematic pins remain; the PCB footprint is unresolved.
2. **P1 cartridge and P4 link connectors:** no verified compatible JLCPCB matches. Their signals and contacts remain in the schematic with unresolved PCB geometry. Generic connectors are not silently substituted.
3. **Requested `@tscircuit/jlcpcb` npm module:** npm returned 404. The available official workflow is `tsci import --jlcpcb --use-exact-footprint`. Genuine generated imports with supplier part numbers and courtyards are used. No fake package or custom component footprint is supplied.

## Electrical and mechanical deviations

Detailed physical pin assignments and manufacturer links are in [PIN-MAPPING.md](docs/PIN-MAPPING.md); electrical checks and unresolved operating limits are in [DATASHEET-AUDIT.md](docs/DATASHEET-AUDIT.md).

| Block | Change from the reference | Remaining qualification |
|---|---|---|
| U2 SRAM | C466866 CY62146EV30LL-45ZSXI; 256 K × 16, 44-pin TSOP, remapped to the original 128 K × 16 bus. JP2 is populated 0 Ω to ground A17. | CPU timing, 200 µs SRAM startup access restriction, loading and compatibility. Original optional BYTE mode is unavailable; JP3 remains an unused legacy header. |
| U4/U8 LDOs | TI TPS74525PQWDRVRQ1 C2865628 replaces NCV8164ASN250T1G; explicit EN/PG/IN/OUT/thermal-pad remap. | PG timing, current limit, output discharge, output noise and current budget differ. |
| U7 audio filters | TI TLV9064IPWR C779410 replaces TLV9364, whose 4.5 V minimum exceeds the reference's 2.5 V VAUD. Same 14-pin quad layout. | Filter response, stability, noise and output loading. |
| U14 timer | MIC1557YM5-TR C144169 follows the upstream BOM instead of the MIC1553 symbol value. | Blink frequency/thresholds; no qualified TI substitution. |
| U9 buffer | Actual noninverting SN74LVC2G34DBVR selected. | The upstream G14 datasheet link describes a different, inverting part. |
| SW1 power | CSS-1210TB C2921710, two-position OFF/ON; correct physical common is pin 3. | Original middle position and nonexistent shield-pad node are omitted. New mechanical actuation differs. |
| SW4/SW5/SW6 | Eight individual Alps SKRRABE010 C125046 switches replace three composite symbols and membrane/contact artwork. | Tactile behavior replaces conductive-pad options; manufacturer underside copper keepouts still need implementation before routing. |
| SW2/SW3 | Exact TE 1825027-5 C86476 is now imported. | Supplier land/hole dimensions and actuation clearance need physical assembly review. Earlier -8 substitution is superseded. |
| VR1/VR2 | JLCPCB trimmer and exact Alps dual volume part use supplier packages; VR2 requires pin remapping. | Wheel/gang continuity and mechanical access need sample confirmation. |
| BT1/SP1 | JLCPCB JST PH two-pin connectors for an external AA holder and speaker. | Original battery/speaker mounting contacts replaced by cables. Speaker remains floating BTL. |
| JP1/JP3/NT1 | Two-pin headers replace solder jumpers; NT1 is a populated 0 Ω joining GND/AGND. | Header/shunt configuration and nonzero net-tie impedance; JP3 does not control the selected SRAM. |
| X1 clock | 4.194304 MHz C718663, larger HC-49S-SMD, 20 pF load. Original 27 pF/33 pF capacitors retained. | CPU oscillator drive, effective load and startup margin are not verified. |
| F1 protection | 1206 fast 2 A 0466002.NRHF C3105 replaces the unimportable original 0805 fuse. | Clearing curve/I²t coordination is not established. |
| Fixed passives/test points | All fixed resistor/capacitor values retained through catalog parts; 100 µF CP parts use MLCCs. Larger JLCPCB test loops replace bare pads. | DC bias, ESR, microphonics, ratings/load budget and assembly accessibility remain open. |
| LCD options | Genuine 40-pin FFC; mounting terminals 41/42 map to the reference's GND-connected pin 0. Z57/Z58 select the original 100 pF option. | Actual display/cable/contact side and the alternative 0 Ω screen configuration remain unqualified. |

The reference export contains U1 GND nodes 129/130 absent from both the 128-pin symbol library and physical package. These two nonexistent nodes are excluded explicitly. The selected SRAM omits its donor-only CE2/NC/BYTE endpoints as documented. P1's alphanumeric C1/C2/S1/S2 use numeric schematic ports 33/34/35/36. Every remaining mapped endpoint is checked against the compiled circuit.

## Board geometry and tool limits

- Board outline and reference centers are enlarged by **1.8**, approximately **236.3 × 130.3 mm**, with four layers and 1.2 mm thickness. The 19 cutout centers move with the board while their individual sizes remain unchanged. This is not shell compatible.
- Actual component package dimensions remain unchanged. Recorded placement offsets clear larger imported parts, courtyards, edges and cutouts. Catalog rotations were compared with reference pin positions; geometry was not rewritten. `lib/placement.ts` and `lib/generated/catalog-orientations.json` record these choices.
- Five upstream bitmap-logo footprints are omitted; written attribution is retained. Original alternative component lands, conductive button artwork and assembly options are not custom-rendered.
- Original 3278 track objects, 548 vias and 108 zones are not imported. Four-layer copper routing and power/ground planes remain unfinished. Power-stage loop placement still needs detailed review despite the enlarged board.
- Minimum routing via copper/hole diameters are configured as **0.45 / 0.30 mm**, with default vias **0.70 / 0.30 mm**. These are configuration checks, not evidence of successfully routed vias.
- Per-chip nested fanout previously triggered a cross-group net lookup error. Region-based fanout phases for U1/U2/P2 are prepared; full-board fanout success is unproven. The routing-difficulty analysis is an estimate, not an autorouter result.
- Importer electrical errors were corrected outside supplier footprint files: TPS22917 is a semiconductor chip, not a mechanical switch; a passive crystal terminal must not require ground; the power-switch schematic uses the manufacturer's common-pin assignment. Custom schematic symbol drawing is not custom PCB geometry.
- Original KiCad DRC crashes on this host with a Swift array-index error, including a retry with explicit font configuration. A clean reference DRC was not obtained.

## Verification status

`reports/current-status.json` and `reports/reference-connectivity.csv` are generated by `bun run audit:reference`. The current design has 245 physical component records, 242 imported courtyards, and three unresolved footprints (U1, P1, P4). The audit compares 830 mapped pin-to-net endpoints across 217 connected nets, and independently checks critical replacement pinouts. Reference NC nets are represented separately.

TypeScript and source netlist checks have passed. The compiler also emits a schematic-layout overlap notice for P2/TP11; it remains a presentation issue to resolve. Placement/build diagnostics are preserved in `reports/`; connector accessibility and generic source metadata warnings still require review. The separate `check:release` deliberately fails while footprints are unresolved or routed copper is absent. An exit code of zero from `tsci build` alone is not a clean DRC.

**Not completed:** independent verification of every connection, proprietary CPU/display electrical qualification, timing/current budgets, copper planes, complete routing, final copper DRC, analog tests and manufacturing validation. No release or fabrication readiness is claimed.

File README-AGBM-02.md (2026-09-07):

# Historical AGBM-02 adaptation

Archived before the tabletop-console scope change. These notes and commands describe historical work; use the main README for the active design. The circuit is now `agbm-02.circuit.tsx`.

Adaptation of [MouseBiteLabs/Game-Boy-Enhance](https://github.com/MouseBiteLabs/Game-Boy-Enhance), AGBM-02 AA-battery revision 1.1, pinned to commit `1c4d928bbfe7ed568c83c68ddea11a5f65f4e830`. Original design and this derivative are licensed under [CC BY-SA 4.0](LICENSE.md).

The KiCad schematic is the connectivity reference; the PCB supplies relative placement, the outline, and cutouts. The extraction retains 240 schematic components. Five schematic sheets cover power, processor/memory/cartridge, controls/link/clock, display, and audio, with labeled functional sections and nets. The four-layer, 1.2 mm board is enlarged by 1.8 around its center to provide placement and routing space. Component packages keep their real dimensions. This enlarged layout does not fit the original shell.

## Current stage

Genuine JLCPCB imports are in `imports/`, created by `tsci import --jlcpcb --use-exact-footprint`. Their footprints and courtyards are retained. Handwritten/custom component footprints are not used. Components without verified catalog replacements remain explicitly unresolved in the schematic; missing PCB geometry is a release blocker, not an approved omission. TI parts are preferred for active circuitry. See the [JLCPCB blocker table](JLCPCB-BLOCKERS.md) and [BLOCKERS.md](BLOCKERS.md).

The reference includes cartridge and link ports, SRAM, LCD FFC, clock, buttons/hotkey logic, battery protection, converters, sequencing, reset, stereo filtering, headphone/speaker amplifier, volume control, and test points. Their connectivity is being audited against manufacturer documentation. A passing netlist comparison alone does not establish electrical correctness.

Required functions must be populated and operational; DNP is not a workaround for an unavailable or unqualified part. The [assembly requirements](docs/ASSEMBLY-REQUIREMENTS.md) record the current controls/display selections, CPU decision and outstanding functional gaps.

The current compiled circuit has 245 physical component records (the three composite button symbols become eight switches), 242 imported courtyards, and three unresolved footprints: U1, P1 and P4. The reference audit checks 830 mapped pin-to-net endpoints across 217 connected nets. These counts do not imply datasheet qualification or completed routing. See `reports/current-status.json`.

## Develop

```sh
bun install
bun run typecheck
bun run check:netlist
bun run check:placement
bun run build
bun run audit:reference
bun run check:release # Expected to fail until the release blockers are resolved
tsci dev agbm-02.circuit.tsx
```

`agbm-02.circuit.tsx` explicitly sets `routingDisabled`; placement must be checked before routing is enabled. Fanout phases for the dense interfaces are defined in `lib/routing.tsx` for later evaluation. Minimum routing vias are configured as 0.45 mm copper diameter / 0.30 mm hole. Do not interpret an exit code of zero from the CLI as a clean DRC: inspect the emitted errors and unresolved component list.

## Reference and audit trail

- `reference/kicad/`: original upstream design files.
- `reference/netlist.xml`: KiCad schematic export.
- `scripts/extract-reference.py`: extraction using KiCad's geometry API.
- `lib/generated/reference.json`: extracted geometry, component pins, and nets.
- `reference/UPSTREAM-AGBM-02.md`: upstream BOM and assembly notes.
- `reports/`: investigation and check results; dated stage reports distinguish current from superseded checks.

No fabrication outputs are released while sourcing, placement, connection verification, and routing remain incomplete.

## Published projects

- [GitHub source and complete KiCad reference](https://github.com/AnasSarkiz/Game-Boy-Enhance)
- [tscircuit project](https://tscircuit.com/AnasSarkiz/Game-Boy-Enhance)

`python3 scripts/publish-registry.py` stages the active `s4/` tree, its reference/license material and audit scripts. Its registry entrypoint exports `s4/power-core.circuit.tsx`. It validates the packaged netlist, placement and build before calling `tsci push`. Historical AGBM-02 files remain on GitHub; all S4 circuit sources and imported parts are included. This publishes a work-in-progress design, not manufacturing approval.

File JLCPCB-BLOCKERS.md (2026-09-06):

# JLCPCB sourcing and import blockers

**Active redesign:** the selected processor is now T113-S4. See the [current S4 JLCPCB table](s4/JLCPCB-PARTS.md). The table below applies to the historical AGBM-02 circuit.

Checked 2026-09-05 with the JLCPCB search/import commands. “No verified match” means no usable exact match was found in these searches; it is not a claim that the part can never appear in the catalog. No custom component footprint is used to fill a missing listing.

## Reference parts without a verified exact JLCPCB match

| Reference | Reference component | Finding | Current implementation |
|---|---|---|---|
| U1 | Nintendo AGB-CPU, 128 pins | No verified listing for the original processor. A similarly named Renesas search result is a different 52-pin MCU. | Original 128-pin schematic retained; PCB footprint unresolved. **Blocks routing/completion.** |
| P1 | Game Boy cartridge slot, including case contacts | No verified compatible listing found. | All original contacts/nets retained; PCB footprint unresolved. **Blocks completion.** |
| P4 | AGB-LINK connector | No verified compatible listing found. | Original link interface retained; PCB footprint unresolved. **Blocks completion.** |
| U2 | Original donor AGB-SRAM | Reference does not specify a purchasable manufacturer part number. Search returns other memories, not an established exact donor match. | C466866, CY62146EV30LL-45ZSXI, imported with explicit address/data/control remapping. Electrical/timing compatibility is still unqualified. |
| U4, U8 | NCV8164ASN250T1G, original SOT-23-5 option | No exact match found. Other NCV8164 packages are listed. | TI TPS74525PQWDRVRQ1, C2865628, imported. Different package, pin mapping, PG timing and analog characteristics are documented. |
| SW1 | CSS-1310B / CSS-1310TB, three-position slide switch | No exact match found under either spelling. | CSS-1210TB, C2921710, imported. Two-position OFF/ON adaptation with the physical common on pin 3. |

Search evidence: `reports/jlcpcb-agb-cpu.json`, `jlcpcb-cpu-agb.json`, `jlcpcb-nintendo-agb.json`, `jlcpcb-cartridge-gba.json`, `jlcpcb-link-exact.json`, `jlcpcb-sram-exact.json`, `jlcpcb-ldo-exact.json`, `jlcpcb-switchpower.json`, and `jlcpcb-switch-exact.json`.

## Listed parts that could not be imported

These are **import failures**, not missing JLCPCB listings.

| Reference / candidate | Catalog item | Import problem | Selected alternative |
|---|---|---|---|
| F1, F0805B2R00FSTR | C5355645 | Exact-footprint import returned “Component not found.” | 0466002.NRHF, C3105; 1206 fast 2 A fuse. Clearing curve/I²t equivalence is unverified. |
| 47 pF capacitor candidate, CL10C470JB8NNNC | C1671 | Exact-footprint import failed. | FCC0603N470J500CT, C5137501. |
| 4.194304 MHz / 12 pF crystal candidate | C700804 | Exact-footprint import failed. | 20 pF C718663 imported; oscillator loading and startup remain blockers. |

The exact **SW2/SW3 shoulder switch 1825027-5 was found and imported successfully as C86476**. It is not an unavailable part. An earlier -8 candidate has been superseded.

## Other blockers

- The requested npm module `@tscircuit/jlcpcb` returned 404. Genuine JLCPCB components are imported with `tsci import --jlcpcb --use-exact-footprint` into `imports/`; there is no fabricated package or custom replacement geometry.
- Routing remains disabled for the placement stage. The missing CPU/connector footprints, pending electrical qualification and button-body copper keepouts prevent a complete routed manufacturing result.
- See [BLOCKERS.md](BLOCKERS.md), [pin mapping](docs/PIN-MAPPING.md), and [datasheet audit](docs/DATASHEET-AUDIT.md) for deviations and tool limitations.

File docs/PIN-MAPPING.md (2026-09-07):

# Physical pin mapping

**Historical circuit finding, 2026-09-07:** the earlier volume-wheel mapping feeds the wipers. The historical S4 audio adaptation (commit ad6b230) corrects this to common pin1, input endpoints pin3/pin5 and output wipers pin2/pin4, with ROUT-based headphone detection. See [the reviewed mapping and sources](../s4/AUDIO-RETENTION-REVIEW.md). The historical root circuit has not been corrected or qualified by this S4 change.

This file describes electrical adaptations, not replacement footprints. All rendered component geometry comes unchanged from `tsci import --jlcpcb --use-exact-footprint`. The machine-readable map is `lib/pin-mapping.ts`; `reports/reference-connectivity.csv` enumerates every mapped reference connection. It is a connectivity record, not proof of complete electrical qualification.

## TI 2.5 V regulators U4 and U8

NCV8164ASN250T1G is replaced by TPS74525PQWDRVRQ1, JLCPCB C2865628. [TI TPS745-Q1 datasheet, DRV pin functions](https://www.ti.com/lit/ds/symlink/tps745-q1.pdf).

| Original pin / role | Imported pin / role |
|---|---|
| 1, VI | 6, IN |
| 2, GND | 3, GND; 7, thermal pad; 2, NC tied to ground as recommended |
| 3, enable | 4, EN |
| 4, power good | 5, PG |
| 5, VO | 1, OUT |

U8 PG still drives U4 EN and U18 ON. U4 PG stays unconnected. Fixed outputs remain VDD2 and VAUD, respectively. PG delay, current limit, output discharge and noise differ; see BLOCKERS.md.

## SRAM U2

CY62146EV30LL-45ZSXI, C466866, is a 256 K × 16, 45 ns, 2.2–3.6 V SRAM. The original CPU addresses only 128 K × 16. [Infineon datasheet, 44-pin TSOP II pin configuration](https://www.infineon.com/assets/row/public/documents/10/49/infineon-cy62146ev30-mobl-4-mbit-256k-x-16-static-ram-datasheet-en.pdf).

| Function | Imported pin numbers, in bit order |
|---|---|
| MA0…MA16 | 5, 4, 3, 2, 1, 44, 43, 42, 27, 26, 25, 24, 23, 22, 21, 20, 19 |
| MD0…MD15 | 7, 8, 9, 10, 13, 14, 15, 16, 29, 30, 31, 32, 35, 36, 37, 38 |
| WE, OE, LB, UB, CE | 17, 41, 39, 40, 6 |
| VDD2 | 11, 33 |
| GND | 12, 34; CE pin 6 remains asserted low |
| A17 / bank select | 18 → original JP2-B net; JP2 is populated 0 Ω to ground |
| NC | 28, explicitly unconnected |

The reference's VDD2-connected CE2 pin 12 has no equivalent on this single-enable SRAM. The replacement is permanently selected as in the reference (CE1 low, CE2 high). Original unused pins 9 and 10 disappear. Original pin 13 is redundant ground and maps to pin 12 with original pin 27. Original pin 47, the optional BYTE configuration contact, has no equivalent; JP3 remains as a labeled, unused legacy header. This revision does not implement an 8-bit SRAM mode. U1's address/data/control nets are preserved. Compatibility and startup timing are not established by this pin table.

## Buttons and switches

Original composite symbols SW4/SW5/SW6 become eight real SKRRABE010 switches (C125046). Each is centered on the reference's four tactile lands, not its membrane artwork. [Alps drawing and circuit](https://tech.alpsalpine.com/cms.media/product_catalog_ta_02_skrr_en_60cbcb0002.pdf).

| Original signal / return | Physical component |
|---|---|
| SW4.1 / SW4.3 | SW_B |
| SW4.2 / SW4.4 | SW_A |
| SW5.1 / SW5.3 | SW_START |
| SW5.2 / SW5.4 | SW_SELECT |
| SW6.1 / SW6.5 | SW_UP |
| SW6.2 / SW6.6 | SW_RIGHT |
| SW6.3 / SW6.7 | SW_DOWN |
| SW6.4 / SW6.8 | SW_LEFT |

For each switch: **signal → pins 1 and 3; GND → pins 2 and 4**. These two internal pairs are explicitly declared. Pressing connects the pairs. No signal is permanently shorted to ground.

SW2/SW3 use the exact TE 1825027-5 (C86476). The earlier -8 candidate is superseded. Pins 1/2 are the switch contacts; imported pins 3/4 are mechanical supports and remain unconnected. The supplier holes are larger than the TE recommended holes and need assembly review. [TE customer drawing](https://www.te.com/commerce/DocumentDelivery/DDEController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).

SW1 uses Nidec CSS-1210TB (C2921710): **physical common is pin 3**, per the manufacturer, not pin 2. Original VBATT pin 1 → new pin 1; original common pins 2/3 → new pin 3; old unused throw 4 → new unused throw 2. The reference's shield pin 5 has no pad in either the original PCB footprint or the new three-contact part and is omitted. OFF/ON operation replaces the redundant middle position of the original three-position part. [Nidec CSS drawings, page 3](https://www.nidec-components.com/e/catalog/switch/css.pdf).

## Audio, display and other interfaces

VR2 uses the same Alps RK10J12R0A0B, C351175, with its supplier numbering: original ROUT 1 → 4, LOUT 2 → 2, LIN 3 → 3, RIN 4 → 5, COM 5 → 1. Supplier 6/7 are mounting terminals, unconnected to circuit nets. Gang numbering and wheel direction need continuity confirmation on a physical sample before assembly. [Alps drawing 4](https://tech.alpsalpine.com/cms.media/product_catalog_rv_03_rk10j_en_780020d1ea.pdf).

VR1 uses Bourns TC33X-2-503E (C913246), 50 kΩ: pins 1/2/3 retain their numbers and pin 2 is the wiper. [Bourns TC33 datasheet](https://www.bourns.com/data/global/pdfs/TC33.PDF).

P2 uses Amphenol 62684-402100ALF (C2931360). Pins 1–40 preserve their numbers. The reference's pin 0 is named AGND **but is wired to the GND net**, so supplier mounting pins 41/42 connect to GND. Contact-side/cable compatibility with the chosen LCD remains unqualified.

P3 uses SJ-3524-SMT-TR (C20182907): 1 sleeve/AGND, 2 tip, 3 ring, 4 tip-normal detection. [Same Sky drawing](https://www.sameskydevices.com/product/resource/sj-352x-smt.pdf).

BT1 and SP1 become JST PH two-pin board connectors (C131337) for external AA holder and speaker. Pin numbering stays 1/2. Both speaker wires remain connected to the BTL amplifier outputs; neither is grounded. JP1/JP3 become two-pin headers (C492401). JP2 is populated 0 Ω (C21189), selecting the lower SRAM bank. NT1 is a populated 0 Ω (C21189) joining GND and AGND through a component instead of a copper net tie.

P1's C1/C2/S1/S2 retain their identity in the reference and use numeric schematic ports 33/34/35/36. U1 pins 129/130 exist only in the exported netlist, not in the 128-pin symbol library or physical footprint, and are explicitly excluded. The CPU's 128 actual pins remain present.

## Importer corrections

The imported TPS22917 is represented as a mechanical switch by the converter. Its six independent semiconductor pins are rendered with a chip primitive while keeping the imported footprint and courtyard. The C718663 crystal import incorrectly marks terminal 2 as ground; it is rendered as a passive two-terminal crystal with both original oscillator connections. Neither correction changes supplier geometry. Import metadata is evidence to inspect, not a datasheet substitute.

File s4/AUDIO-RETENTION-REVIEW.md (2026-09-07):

# Retaining Enhance audio around the S4

**Historical handheld revision (`ad6b230`):** superseded by the user-authorized tabletop console. The 33-part analog audio section is no longer active. See [current console review](CONSOLE-REVIEW.md). All counts and checks below describe that historical revision.

The current working design has **145 components**. It adds 33 audio components to the previously published 112-component S4 stage. Twenty original Enhance designators have explicit counterparts. **This working revision has unresolved tool diagnostics and is not published or ready to route.** Registry v1.0.3 remains the earlier stage.

## What is retained

The TI LM4853MM/NOPB amplifier, Alps RK10J12R0A0B volume wheel, Same Sky SJ-3524-SMT-TR headphone connector, speaker connector, stereo input/output coupling, feedback, headphone detection and speaker coupling follow the original functions. Existing genuine JLCPCB imports are copied byte-for-byte, including courtyards and mounting lands. The already-selected TI TPS74525PQWDRVRQ1 supplies the original nominal 2.5 V audio rail from SYS_3V3. No original Nintendo signal or 5 V enable is directly connected to an S4 GPIO.

`audio.json` records every new designator, original designator, MPN and supplier number. `reports/enhance-retention.csv` accounts for **all 240 original components**. Its pending rows remain required review work, not authorization to remove functions or designate parts DNP.

## Required connection changes

1. **Audio source:** S4 HPOUTL99/HPOUTR98 feed new 1 µF coupling capacitors before the potentiometer. Its native DAC replaces the Nintendo PWM buffers, reconstruction filters and associated bias network. Manufacturer family documentation identifies the outputs and the pseudo-differential HPOUTFB100 input. The [100ask development-board schematic, page 1](https://dl.100ask.net/Hardware/MPU/T113s3-Industrial/T113-S3_Industrial-DevKit_V11.pdf) provides the 100 nF feedback-to-ground coupling and 100 nF/22 Ω series shunts on each headphone output. These were checked visually. Exact S4 output levels, drive stability, codec setup and ground-return layout still need qualification.
2. **Volume wheel:** The [Alps drawing 4](https://tech.alpsalpine.com/cms.media/product_catalog_rv_03_rk10j_en_780020d1ea.pdf), viewed from the mounting side, identifies a common end and two independent wipers. In the imported pad numbering, common=1, channel A endpoint/wiper=3/2, channel B endpoint/wiper=5/4. The earlier adaptation fed the wipers and took output from the endpoints. The S4 version feeds endpoints and takes output from wipers. Added coupling avoids applying the codec's DC bias to this AC-use volume part. The raw imported symbol and geometry remain unchanged. Channel tracking, knob direction and continuity still need a physical sample check.
3. **Headphone detection:** [TI LM4853, HP-IN Function](https://www.ti.com/lit/ds/symlink/lm4853.pdf) requires detecting insertion from its ROUT output. The retained jack switches the tip, normally used for left audio. Therefore S4 left audio intentionally uses the amplifier's internally named right channel and then the jack tip; S4 right audio uses its left channel and the ring. Stereo heard by the user stays correct. The jack's normal contact is conditional and must not be represented as a permanent short between pads 2/4. The [Same Sky drawing, page 2](https://www.sameskydevices.com/product/resource/sj-352x-smt.pdf) was inspected from the previously downloaded manufacturer file.
4. **Shutdown:** An imported MMBT3904LT1G NPN, 1 kΩ base resistor and 100 kΩ base-emitter pull-down replace the VDD5-driven MOSFET. S4 PG0/pin120 requests audio enable; the 100 kΩ pull-up to AUDIO_2V5 disables the amplifier until firmware drives the transistor. The 2.5 V shutdown node is separate from the 3.3 V GPIO. Firmware must initialize and settle the codec before enabling playback.
5. **Supply/returns:** The [TI TPS745-Q1](https://www.ti.com/lit/ds/symlink/tps745-q1.pdf) fixed 2.5 V part uses IN6, OUT1, EN4, GND3/EP7 and grounded NC2; unused PG5 stays unconnected. Input bypass is 1 µF, output/bulk bypass 10 µF and local amplifier bypass 100 nF. The prior external enable sequence changes to SYS_3V3, while firmware controls amplifier shutdown. GND is the common electrical net; separate analog return placement and decoupling are still required. This does not connect audio load to the CPU's internal 1.8 V supply.

## Retained limits that require testing

- The retained 100 kΩ input/20 kΩ feedback pair has nominal single-ended gain 0.2. This may be too quiet with S4 output levels. Gain and clipping must be measured before claiming the volume range is satisfactory. It was not silently increased.
- The retained 100 µF headphone capacitors give about 51 Hz corner frequency for 32 Ω headphones with the 1 kΩ bleeds. The speaker's 100 µF series capacitor gives about 199 Hz at 8 Ω. Actual MLCC capacitance under DC bias may be lower. These are calculations, not measured frequency response.
- Speaker wires remain floating between the amplifier outputs, with the reference's series capacitor. Neither wire is grounded. Headphone insertion must disable bridge operation without oscillation, pops or DC across the speaker.
- The 2.5 V regulator's lower specified tolerance is 2.4625 V, above the amplifier's 2.4 V minimum in steady state. This does not qualify startup, dropout, transient margin, current or thermal budgets. No amplifier output-power claim is made.

## Tool blockers

The imported volume wheel has two SMT mounting lands numbered pin6 and two separated plated mounting slots numbered pin7. They are genuine supplier geometry and remain unconnected. The installed core emits two `source_ambiguous_port_reference` records because it expects each port's multiple pads to overlap. The record type does not end in `_error`; the audit and publication gate now also check `error_type`, so these findings cannot be missed by a suffix-only check.

The raw dual-gang volume import uses a chip primitive, so the tool also emits `source_no_power_pin_defined_warning`. Giving a passive pot a fake power connection would be incorrect. The existing potentiometer primitive describes two/three-pin parts, so this five-electrical-terminal dual-gang part needs proper passive component support. No single-gang substitute, mounting-pad deletion, fake supply or diagnostic suppression is used to bypass these issues.

The correct next tooling work is support for passive multi-gang components and unconnected, repeated mechanical-terminal pads. Placement and electrical path checks can still be performed, but the complete acceptance audit deliberately fails until the tool represents this component correctly.

## Reproduce

The final placement review covers 145 populated parts and 145 courtyards, with a minimum courtyard gap of 0.1044 mm. The independent comparison checks 75 net groups and 401 connected endpoints, including the reviewed audio paths and 69 allocated processor signals. TypeScript and CLI placement checks pass. The seven sheets and PCB preview render; these visual checks do not qualify analog performance or power integrity. Two ambiguous-port errors and one passive-component warning remain in the compiled circuit and cause both acceptance audits to fail.

Routing remains disabled: there are no traces or vias and no copper-short DRC result. The registry publisher retains its 112-component release gate; packaging/reproduction inputs must be reviewed for a future audio release after the tool blockers are fixed. Do not publish this draft by loosening that gate.

The routing-difficulty and DXIN distance reports were refreshed for this 145-component draft. DXIN still totals 10.46 mm across three estimated branches. These are pre-routing estimates, not routed timing or success guarantees; the older baseline review retains its dated observations.

```sh
python3 scripts/prepare-s4-audio.py
bun run generate:s4:core
bun run typecheck
bun run audit:s4:imports
bun run check:s4:netlist
bun run check:s4:placement
bun run build:s4:core
python3 scripts/audit-s4-audio.py
bun run audit:s4:core
python3 scripts/audit-s4-retention.py
bun run preview:s4:sheets
```

The audio/core acceptance audits currently return nonzero for the unsuppressed volume-control findings. A zero CLI build exit status must not be reported as a clean DRC.

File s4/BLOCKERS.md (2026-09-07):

# S4 console blockers — 2026-09-07

**Do not fabricate.** The active 103-component tabletop core passes its placement and connection checks, but the console is incomplete and unrouted. See [console review](CONSOLE-REVIEW.md) for evidence, scope changes and LED behaviour.

| ID | Finding | Required next action |
|---|---|---|
| S4-01 | Exact C41411351 import remains unavailable. The authorized C5197687 S3 geometry has a 5.5999888 mm exposed land, versus 5.72 mm in the S3 drawing. | Qualify the exact S4 package, exposed pad, stencil, orientation and assembly process. The MPN is S4; that alone does not qualify the land pattern. |
| S4-02 | Reference pin/voltage information is from S3-family documentation; exact S4 limits and sequencing remain unconfirmed. | Obtain authoritative T113M4020DC0 documentation and qualify supplies, resets, pinmux and 256 MB memory startup. |
| S4-03 | The upstream reference has three ERC errors and unresolved source-library/identity findings. | Complete independent electrical review; retain reference ERC evidence and do not claim a verified source board. |
| S4-04 | Reference R8/R9 ADC divider values/source are undefined. | Specify the actual monitored rail, ratio and input protection if retained; do not represent this with TODO or DNP parts. |
| S4-05 | 57 processor signal allocations are checked. HDMI and debug reservations remain unwired. The LEDs have an integration fragment, not a bootable tested image. | Finish the interfaces and real S4 device tree, USB/HDMI drivers, fault reporting and emulator validation. |
| S4-06 | ADV7513BSWZ/C408901 is only an imported candidate. No connected HDMI transmitter, connector, dedicated supply/filtering, protection or verified timing exists. | Finish a manufacturer-based HDMI subsystem with RGB/I²S input, DDC/HPD/control, power and protection. Verify display/audio driver compatibility before layout sign-off. |
| S4-07 | Product scope changed to a tabletop console. Original LCD, cartridge/link, battery, onboard game buttons and analog speaker/headphone/volume functions are removed/replaced. | Deliver TV picture/audio and USB game control. Original shell/cartridge compatibility is not promised; no DNP is used to hide the changes. |
| S4-08 | No routed copper, planes, impedance/length matching, via fanout or copper-short DRC exists. | Complete electrical qualification, then fanout/routing and manufacturing review. Keep minimum vias 0.45/0.30 mm. |
| S4-09 | USB1 now has a TI 500 mA host switch, fault indication and reservoir, but USB-C Rd plus the 1 A input PTC does not establish source capability, controlled inrush or a whole-console budget. | Add/qualify source-current management and power/reset behaviour under startup, overload, brownout and controller hot-plug. Do not enable the host on a prototype before qualifying the source. |
| S4-10 | Zetta storage import pitch is 1.27 mm versus the manufacturer's 1.25 mm; external capacitance wording remains unresolved. | Qualify solder lands, capacitance, boot/storage timing and firmware. Preserve raw supplier geometry. |
| S4-11 | Automatic schematic packing and sheet-centre rendering have known limitations. | Current explicit relative layout and separately rendered centred sheets avoid these issues through supported APIs; review the visual outputs after every layout change. |
| S4-12 | The earlier dual-gang volume import emits ambiguous mechanical-terminal and passive-chip warnings. | Historical upstream issue only: this part is absent from the user-authorized tabletop scope. No diagnostic is suppressed in the active circuit. |
| S4-13 | Green LED C2986011's raw symbol reverses its numbered polarity. | Addressed in a typed LED wrapper: manufacturer 1=anode/2=cathode, original footprint unchanged. Bench-check assembly polarity/brightness. |
| S4-14 | C2345 USB-A manufacturer's linked drawing could not be retrieved; standard USB pinout and catalog/import agree but detailed package qualification remains open. | Obtain and review the drawing; qualify wave/through-hole soldering and connector mechanics. |
| S4-15 | Supplier LED and Panasonic reservoir lands differ from manufacturer suggested pads. | Qualify fit/stencil/assembly. Do not redraw supplier footprints to conceal the differences. |

The active audits inspect all error/warning records, including types containing `error_type` without an `_error` suffix. Build success alone is not release acceptance. All 103 parts have courtyards, with 0.1044 mm minimum spacing; all 41 available imports pass geometric checks. Firmware operation, analog/USB performance and assembly shorts require a real prototype.

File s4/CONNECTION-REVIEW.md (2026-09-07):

# S4 connection review

**Current scope:** the active 103-component tabletop core is reviewed in [CONSOLE-REVIEW.md](CONSOLE-REVIEW.md). The earlier handheld audio and ten GPIO controls described in the historical reviews are no longer active.

A 103-component console core is implemented; this remains a qualification review, not sign-off for every console connection. All physical pin numbers below come from the pinned Trellis schematic and the linked S3 family documentation. S4-specific electrical confirmation remains required. `reports/reference-cpu-pins.csv` lists all 129 reference CPU pins without marking them datasheet-qualified.

## Power and startup

The reference uses two [TI TLV62569PDDCR converters](https://www.ti.com/lit/ds/symlink/tlv62569.pdf), whose SOT23-6 pins are EN=1, GND=2, SW=3, VIN=4, PG=5 and FB=6. The generated JLCPCB import matches these pin names and numbers. The 0.6 V feedback equation gives **3.318 V** with 453 kΩ/100 kΩ, and **0.906 V** with 51 kΩ/100 kΩ. These are nominal values; tolerance, transients and current budgets are not verified.

The reference's 3.3 V converter PG drives the core converter EN. The core PG is unconnected, while CPU RESET uses a separate RC/pushbutton. The new stage moves R11.1 from 3.3 V to LDOA 1.8 V because RESET is in the VCC-RTC domain (Allwinner table 4-2). Do not assume this guarantees reset during every brownout; qualification needs the S4 reset thresholds and timing. Switching current loops and decoupling must remain short even on a larger board.

| Reference net | CPU physical pins | Treatment |
|---|---|---|
| +0V9 | 46, 51, 81, 116, 117 | Core/system supply from its converter; confirm S4 limits and required clock/voltage configuration |
| +1V5 | 30, 48, 49 | Reference internal LDOB output to DRAM supply; do not connect an external regulator in parallel |
| +1V8 | 20, 26, 28, 50, 65, 89, 97, 107 | Reference LDOA output and consumers; current budget must be established before adding loads |
| +3V3 | 29, 34, 66, 77, 83, 128 | LDO input and I/O supply domains |
| GND | 91, exposed pad 129 | Both require real copper connections; the EP cannot be omitted |

The HDMI transmitter must not be attached to the CPU's internal 1.8 V output without a qualified load budget. Its own 1.8 V supply/filtering is an unresolved design requirement.

## Interface allocation

The [family pinmux table](https://dl.linux-sunxi.org/T113-S3/T113-S3_Datasheet_v1.6_20220303.pdf) shows PD7/PD8 (physical 62/63) serving UART4 and display functions. The new [pin allocation](pin-allocation.json) reserves PE4/PE5 for UART4 instead. Board IDs move from PD21/PD22 to PE8/PE9. The audit checks 57 unique signal allocations against physical CPU labels and verifies reserved pins remain unwired. RUN/ERROR indicators use PE0/PE1; LCD RGB24/sync, I²S1, HDMI control and USB1 remain reserved for unfinished circuitry. S4 firmware/pinmux confirmation remains required. In particular, I²S1 DOUT0 uses **PG15**, not PG14 in the family function-2 mapping.

The reference storage occupies SDC0 on PF0–PF5. It cannot simply be paralleled with another microSD device. A second storage device needs a separate supported bus, or the storage architecture must be deliberately changed. The reference uses 51 kΩ pulls, a clock gate for recovery, and a 22 Ω series clock resistor; the implemented Zetta 512 MB device pin map and pull range have been checked against its manufacturer document; clock timing and actual boot firmware remain unqualified. See [interface review](INTERFACE-REVIEW.md).

USB0 pins 114/115 are DM/DP; USB1 pins 113/112 are DM/DP in the reference. A console needs a powered host port for a controller plus a deliberate power/recovery connection, with correct VBUS direction, current limiting and protection. Do not connect 5 V VBUS to a 3.3 V GPIO. The reference USB-C Rd resistors alone do not authorize an arbitrary high-current load.

## HDMI candidate

[ADV7513 Rev B](https://www.analog.com/media/en/technical-documentation/data-sheets/ADV7513.pdf) supports digital video and audio. Its exposed pad is electrical ground. The genuine import names four negative TMDS pins generically; the manufacturer mapping is **17=TXC−, 20=TX0−, 23=TX1−, 26=TX2−**. These are connected differential outputs, not NC pins. Keep the supplier footprint unchanged and use physical pin mappings when wiring.

Supply pins 1/11/31/51, 12, 13 and 15/19/25 require 1.8 V; pin 29 requires 3.3 V. The imported metadata alone does not enforce these voltage domains. Full application support, clock/video format, I²S audio, DDC/HPD, configuration/interrupts and required unused-input termination remain open. Do not replace this function with a video-only TFP410 and claim HDMI audio.

## Existing Enhance circuitry disposition

| Function | S4 redesign requirement |
|---|---|
| Nintendo CPU and external SRAM | Replace with S4 execution and its in-package RAM; verify RAM initialization and test all 256 MB |
| Power/clock/reset | New S4 rails, 24 MHz/32.768 kHz reference clocks and qualified recovery/reset; original 4.194304 MHz CPU clock is unsuitable |
| Buttons and controllers | Retain required game inputs through qualified GPIO switches or USB controller support, including A/B, directions, Start/Select and shoulders; no DNP |
| Headphones/speaker/volume | Requalify codec output, amplifier input level, supply and volume behavior; old 2.5 V analog circuitry cannot be assumed compatible |
| Display | HDMI subsystem and compatible monitor are the current console target; original Nintendo LCD/FFC compatibility is unimplemented |
| Game/save storage | Resolve flash identity and provide usable ROM/save storage with tested boot and recovery |
| Cartridge and link | Original hardware protocols are not preserved automatically by an emulator; remain an explicit compatibility gap |
| Battery/USB power | Console power source and full load budget need specification; do not carry over the original AA converter or parallel power sources blindly |

## Verification boundary

No cross-net duplicate pins or incorrect assignments within the audited reference supply sets were found. Copper, soldering, signal integrity, complete operating limits and peripheral firmware were not tested. Required tests after implementation include disconnected/shorted-net detection, footprint pin mapping, power-domain checks, pinmux conflicts, placement/courtyards, routing completeness, USB/HDMI return paths, and an assembled-board functional test.

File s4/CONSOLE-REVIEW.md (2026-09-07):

# Tabletop console and indicators — 2026-09-07

The user approved changing the product from a handheld to an HDMI console with USB controllers. The active design now has **103 populated components, 54 nets and seven schematic sheets** on a **130 × 110 mm, four-layer** placement board. Routing stays disabled; minimum via copper/hole remains 0.45/0.30 mm. This is a connected console core, not a working or fabrication-ready console. HDMI and complete firmware are still required.

## Scope change

The 33-part analog audio section and 30-part onboard game-input section are removed from the active circuit. Sound/volume move to the TV, and game controls move to USB controllers. The volume-wheel import limitation remains an upstream issue, but no longer affects this product's active circuit. These are user-authorized product changes, not DNP entries or hidden DRC workarounds. The older audio files/reports describe commit `ad6b230`; they are not current acceptance results.

The S4 CPU, in-package RAM, TI regulators, clocks, storage, reset and USB-C recovery remain. The original Nintendo CPU/SRAM, cartridge/link compatibility, handheld LCD, speaker/headphones, battery operation and original shell are outside the new console scope. The default root entrypoint now selects the console; `agbm-02.circuit.tsx` preserves the historical Nintendo adaptation.

## Indicators

| Label / part | Color | Actual meaning | Connection |
|---|---|---|---|
| POWER / D1 | Yellow-green | SYS_3V3 is present; does not prove the core rail or boot is healthy | SYS_3V3 → anode1; cathode2 → R4 1 kΩ → GND |
| RUN / LED2 | Yellow-green | Linux heartbeat once the GPIO LED driver starts; not application/game health | PE0 / physical44 → 10 kΩ → Q2 base; 100 kΩ base pull-down; 1 kΩ LED series resistor |
| ERROR / LED3 | Red | Software-requested fault or kernel panic when integrated; cannot detect every failure | PE1 / physical45 → 10 kΩ → Q3 base; 100 kΩ base pull-down; 1 kΩ LED series resistor |
| USB FAULT / LED4 | Red | TPS2051B asserts its active-low fault output during overload/thermal protection; independent of firmware | LED cathode through 1 kΩ to OC3; OC has 10 kΩ pull-up to 3.3 V and goes to PG9 / physical4 |

RUN and ERROR use imported onsemi MMBT3904LT1G NPNs. [The manufacturer pinout](https://www.onsemi.com/download/data-sheet/pdf/mmbt3904lt1-d.pdf) is B1/E2/C3. The external base pull-downs keep the indicators off while the GPIOs are undriven. Firmware can still light them during boot if it drives the pins; this circuit does not override software. The GPIO sources approximately 0.26 mA at a nominal 0.7 V base drop. The collectors carry LED current rather than loading the processor pins directly.

Each LED has its own 1 kΩ, 1% series resistor. At a nominal 2 V forward drop, power LED current is about 1.3 mA; transistor voltage drop reduces RUN/ERROR current slightly. Even the conservative zero-forward-drop bound at 3.6 V is 3.64 mA with a 990 Ω resistor, below the LEDs' 25 mA rating. Brightness at this low current needs prototype evaluation. ERROR being dark is not proof that a stalled or unpowered processor is healthy.

### Datasheet corrections without footprint changes

[Everlight DSE-0025740, page 5](https://www.everlighteurope.com/custom/files/datasheets/DSE-0025740.pdf) specifies the green LED's physical **1=anode, 2=cathode**. The C2986011 raw import reverses the symbol labels (`C` on pin1, `A` on pin2), while its pad positions and polarity artwork match the manufacturer numbering. `GreenIndicator` preserves every supplier pad/courtyard and supplies the correct LED primitive, polarity and attributes. The original source import is unchanged. The old D1 used the opposite terminal convention, so its reference mapping is explicitly reversed. Its former 5.1 kΩ R4 becomes an imported 1 kΩ part.

[Everlight DSE-0014128, page 6](https://datasheet.octopart.com/19-217-R6C-AL1M2VY-6T-Everlight-datasheet-192340706.pdf) confirms red LED C2986060 also uses 1=anode, 2=cathode. Both package diagrams were rendered and visually checked. The raw red import already uses the correct LED representation. Supplier LED pads are larger than the suggested manufacturer lands; stencil/assembly fit remains a qualification item. No custom footprint is drawn.

## Controller port

One native USB2 Type-A port J4 is connected to USB1. Further controllers require a compatible external hub or a future onboard hub design; two USB devices must never be connected in parallel to one data pair. USB-C J1 remains the power/recovery/device connection.

[TI TPS2051BDBVR, table 5-1](https://www.ti.com/lit/ds/symlink/tps2051b.pdf) uses OUT1, GND2, OC3, EN4, IN5 and an active-high enable. U9 is supplied from INPUT_5V after the existing input PTC. PG10 / physical5 enables it, with R55 100 kΩ holding it off by default. Its nominal load rating is 500 mA; its current-limit threshold is approximately 1 A, not a precision 500 mA clamp. Input, output, enable, fault, 3.3 V and ground are independently checked as separate nets. No processor GPIO is connected to 5 V.

The imported switch primitive is changed to an electrical chip representation because this semiconductor has five independent pins. Supplier geometry is unchanged. The USB fault LED plus pull-up loads OC by approximately 1.6 mA nominal; TI specifies its low-level output at 5 mA. Its deglitching means brief transients need not appear on the LED.

ST USBLC6-2SC6 U10 provides ESD paths 1–6 for DM and 3–4 for DP, GND2 and VBUS5, following the [ST datasheet](https://www.st.com/resource/en/datasheet/usblc6-2.pdf). J4 uses standard USB2 contacts 1=VBUS, 2=DM, 3=DP, 4=GND; imported shell terminals5/6 join ground. Supplier catalog and import agree. **The connector manufacturer's linked PDF could not be retrieved (403/HTML response), so its detailed mechanical/pin drawing still requires review.** Its catalog specifies wave soldering: assembly process must accommodate its through-hole contacts.

C70/C71 provide 100 nF/10 µF input bypass; C73 provides 100 nF output bypass. C72 is Panasonic EEEFT1A221AP/C401764, a **polarized 220 µF, 10 V, ±20%** reservoir. Its positive imported pad1 connects to host VBUS and negative2 to ground. The [Panasonic FT specification](https://industrial.panasonic.com/cdbs/www-data/pdf/RDE0000/ABA0000C1240.pdf) gives at least 176 µF initial capacitance at the specified measurement condition. The import's 3.50 × 1.20 mm pads differ from Panasonic's suggested 3.20 × 1.60 mm lands; fit/stencil qualification remains open. This capacitor is represented as polarized, not an interchangeable two-terminal capacitor.

The host circuit does not solve the main input-power budget. The existing USB-C Rd and 1 A PTC do not establish the available source current, controlled inrush, or sufficient current for the processor, HDMI and USB load. Do not enable the host on hardware before qualifying source-current management and startup. Routing must also shorten the protection return and power-switch loops and meet USB differential impedance.

## Firmware integration

`firmware/console-leds.dtsi` provides a GPIO LED fragment using the [Linux binding](https://raw.githubusercontent.com/torvalds/linux/master/Documentation/devicetree/bindings/leds/leds-gpio.yaml). PE bank index4, pins0/1, use active-high drive. RUN requests the heartbeat trigger; ERROR starts off and has `panic-indicator`. The actual kernel needs GPIO LED, heartbeat and panic-trigger support. An application/service must explicitly report application errors to ERROR; no such service or complete boot image is claimed here.

This fragment must be integrated with the real S4 board device tree and pin configuration. It has not been compiled into a DTB or tested on hardware; `dtc` is unavailable locally. The host also needs USB1 PHY/host and VBUS regulator integration plus fault handling. GPIO assignments are checked against the S3-family pin tables; exact S4 qualification remains open.

## Checks and limits

- TypeScript, CLI netlist and placement, build, geometry audit and independent console/core connection audits pass without emitted errors/warnings.
- All 103 placed parts have courtyards; minimum courtyard separation is 0.1044 mm. All 41 available supplier imports pass the geometric checks.
- The independent comparison checks 54 net groups, 304 connected endpoints and 57 allocated processor signals. The console audit separately checks polarity, limiting resistors, transistor pulls, switched power separation and USB data paths.
- Seven schematic sheets are rendered. PCB, indicators and USB host views are reviewed; this is not signal-integrity, timing or thermal validation.
- The pre-route congestion estimate peaks at 5.9% near C19; this is a solver heuristic, not a routing success rate. DXIN has 10.46 mm total estimated straight-line branches, not a measured copper length.
- No routed traces/vias or copper-short DRC exists. HDMI, input-current management, debug access, reset/brownout qualification, exact S4 documentation and a tested emulator image still block manufacturing.

The registry stays at v1.0.3 until its package boundary and publication gate are updated and the revised draft is explicitly packaged. The GitHub working design is newer.

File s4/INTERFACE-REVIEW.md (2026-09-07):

# USB, storage, recovery and game-input review — 2026-09-07

**Historical v1.0.3 baseline:** the counts and measurements below describe the published 112-component stage. The current 103-component tabletop draft replaces onboard controls and analog audio with USB controllers and planned HDMI sound; see [console review](CONSOLE-REVIEW.md). The historical figures below are not current acceptance results.

The connected stage contains **112 components, 50 nets and 313 connected endpoints**. The library contains 25 genuine supplier imports, including the currently unwired HDMI candidate. No imported footprint was redrawn. There are six schematic sheets/sections and ten populated game switches. This review checks selected connections; it does not establish a working console or authorize fabrication.

## USB-C power and recovery

J1 is Hanxia HX-TYPE-C-16P-L8.35, C41427493. Its [manufacturer drawing](https://datasheet.lcsc.com/datasheet/pdf/efa6a1897252d50751d6c1739fcd6844.pdf?productCode=C41427493) was inspected for the solder tails, shell stakes and locating holes. The reference's alphabetic contacts map to the supplier's physical numbering:

| Reference contacts | Imported pads | Connection |
|---|---|---|
| A1/B12; A12/B1 | 5; 7 | GND |
| A4/B9; A9/B4 | 6; 8 | USB_C_VBUS_5V |
| A5; B5 | 15; 9 | Separate 5.1 kΩ Rd resistors to GND |
| A6/B6 | 13/11 | USB0_DP, CPU115 |
| A7/B7 | 12/14 | USB0_DM, CPU114 |
| Shield | 1–4 | GND |
| SBU | 10/16 | Deliberately unconnected for USB2-only use |

The two locating holes remain nonplated. All four shield slots remain plated. Courtyard checks now cover both kinds of holes as well as SMT pads.

U4 is ST USBLC6-2SC6, C2827654. The [ST datasheet](https://www.st.com/resource/en/datasheet/usblc6-2.pdf) confirms continuous internal paths 1–6 and 3–4, GND2 and VBUS5. The wrapper represents those internal connections; the audit independently joins the two reference net segments for each USB data conductor. These are continuous USB nets, not signals routed through an active buffer. Short protection return paths and USB differential routing remain required.

F1 is the reference JK-nSMD100-16, C369161, a 1 A hold/16 V resettable fuse. It connects USB_C_VBUS_5V to INPUT_5V. It is not a USB current-negotiation or inrush-control circuit. The source-current budget, CC current detection, controlled startup, voltage drop and protection coordination remain unresolved. The Rd resistors alone do not establish permission to draw the full console load. USB0 is the recovery/device interface; a separately powered USB1 host port is still required for controllers.

## Storage and FEL recovery

U5 is **Zetta ZDSD04GLGEAG / C2875854: 4 Gbit, or 512 MByte**. The reference's displayed ZDSD08 name and unrelated XTX link are superseded by the [Zetta family datasheet](https://datasheet.lcsc.com/datasheet/pdf/cda7e97f747983cf44624654eba01fb9.pdf?productCode=C2875853), which includes the 04G ordering code. Its top-view mapping is:

| Storage pad | Signal | Connection |
|---|---|---|
| 1 | DAT2 | SDC0 data2 / PF4 |
| 2 | DAT3 | SDC0 data3 / PF5 |
| 3 | CLK | U6 output through R23, 22 Ω |
| 4 | GND | GND |
| 5 | CMD | SDC0 command / PF3 |
| 6 | DAT0 | SDC0 data0 / PF1 |
| 7 | DAT1 | SDC0 data1 / PF0 |
| 8 | VDD | SYS_3V3 |

The 2.7–3.6 V supply range covers nominal SYS_3V3. The retained 51 kΩ CMD/data pulls fall within the specified 10–100 kΩ range. The device supports up to 50 MHz, but that does not qualify this board at 50 MHz: host timing, gate delay, capacitance and routing must also pass. Power-up initialization and Linux/U-Boot operation have not been tested.

The manufacturer package drawing uses 1.25 mm pad pitch; the supplier import uses 1.27 mm. The imported lands are wider than the device terminals, but assembly/stencil qualification is still required. Its stated maximum power-line capacitance also needs interpretation against the reference's external 10 µF C41. Neither issue was hidden by altering the supplier geometry or silently changing the reference capacitor.

U6 is TI SN74AHC1G08DCKR / C122838. The [TI datasheet](https://www.ti.com/lit/ds/symlink/sn74ahc1g08.pdf) confirms A1, B2, GND3, Y4 and VCC5, with operation from 2–5.5 V. PF2 drives A; R22 pulls B to SYS_3V3, C44 filters B to GND, and SW2 grounds B when pressed. Y drives the storage clock through R23. Suppressing the storage clock is intended to support reference FEL recovery; actual boot-ROM fallback and recovery still need an S4 hardware test.

## Game inputs and shared pin allocation

`controls.json` defines directions, A/B, Start/Select and L/R. Each uses an imported TSA010A2026B switch, a 5.1 kΩ SYS_3V3 pull-up and a 100 nF shunt capacitor. A closed switch grounds the input. Nominal RC time is 0.51 ms; firmware debounce remains necessary. All ten pressed pull-ups draw approximately 6.5 mA in total.

The [Allwinner family pin tables](https://dl.linux-sunxi.org/T113-S3/T113-S3_Datasheet_v1.6_20220303.pdf) supply the physical GPIO mappings. `pin-allocation.json` reserves display, audio, debug, HDMI control and USB-host signals without connecting unfinished peripherals. All 65 allocations are unique and checked against compiled CPU pin labels. Board-ID2 moves U3.53 → U3.39 (PE8); board-ID3 moves U3.52 → U3.38 (PE9). Software must reflect both changes. Original S4 qualification remains open; an S3-family pin table is not a substitute for S4 operating limits or testing.

## Placement and tool checks

The 110 × 110 mm board stays at four layers, routing disabled, with minimum via diameter/hole of 0.45/0.30 mm. Controls sit around the perimeter; USB-C is on the bottom edge and storage is beside the CPU. Imported courtyards cover all 112 placed components with at least 0.10 mm separation. This spacing check does not qualify power loops or signal integrity.

The build emits no errors or warnings for this stage. The independent audit checks every expected connected endpoint, exact procurement identity, required supplies, forbidden NC pins, internal USB paths, game inputs, pin allocation and courtyards. No copper routing or short-circuit DRC has been performed.

Manual sheet positions require explicit board `schLayout={{ layoutMode: "relative" }}`: the installed core otherwise selects packing because it does not see coordinates nested inside sheets. The schematic renderer centers page borders at the origin even when a sheet has a different recorded center. The generator now keeps content within those borders. `bun run preview:s4:sheets` renders each sheet separately; all six were visually reviewed. No diagnostics were suppressed.

## Remaining console work

HDMI video/audio and its independent supplies/protection, powered USB1 controller access, UART debug access, ADC measurement, full input-power/current management, reset/brownout qualification and firmware remain incomplete. Fanout, routing, impedance checks and a populated prototype follow electrical and placement qualification. None of these functions is marked DNP or claimed to work.

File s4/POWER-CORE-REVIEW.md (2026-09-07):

# Connected power, CPU and interface stage

**Historical v1.0.3 baseline:** the counts and measurements below describe the published 112-component stage. The current 103-component tabletop draft replaces onboard controls and analog audio with USB controllers and planned HDMI sound; see [console review](CONSOLE-REVIEW.md). The historical figures below are not current acceptance results.

Entry: `power-core.circuit.tsx`. This is an **incomplete console**, with 112 populated components, six schematic sheets/sections and routing disabled on a 110 × 110 mm, four-layer placement board. Minimum via settings remain 0.45/0.30 mm. No manufacturing outputs are released.

## Implemented and checked

The exact JLCPCB imports supply all component footprints and courtyards. The S4 CPU retains C5197687 geometry but orders **T113M4020DC0 / C41411351**. The audit compares 313 connected endpoints across 50 net groups: 40 reference-derived groups plus ten game-input groups. Documented reset, board-ID and USB solder-tail/internal-path mappings are applied independently in the audit. It checks procurement identities, every CPU supply/ground role, NC106, courtyard separation and emitted DRC diagnostics.

The two TI TLV62569PDDCR stages include inductors, input/output capacitors, feedback resistors, feed-forward capacitors, enable pulls, power-good sequencing and the status LED. Nominal calculated outputs are 3.318 V and 0.906 V. Feedback lower resistors are 100 kΩ, below TI's 200 kΩ recommendation. The retained 10 pF feed-forward capacitors differ from TI's 6.8 pF example; loop stability and load transients still need qualification. [TI datasheet, section 8.2](https://www.ti.com/lit/ds/symlink/tlv62569.pdf)

CPU supply inputs now require connections; pins 28/30 are internal-LDO outputs, pins 91/129 require ground, and pin 106 must remain unconnected. Exact S4 voltage tolerances are not asserted. R11.1 moves from 3.3 V to 1.8 V because RESET belongs to VCC-RTC. The family document requires reset hold after rails settle; the retained RC network has not been proven to meet startup or brownout timing. [Allwinner tables 4-2/5-2 and section 5.12](https://dl.linux-sunxi.org/T113-S3/T113-S3_Datasheet_v1.6_20220303.pdf)

Both clocks use standard crystal primitives/symbols with unchanged imported footprints. The 24 MHz part has a catalog load specification of 8 pF. The RTC part is 32.768 kHz/12.5 pF; its imported 1.0 × 1.8 mm lands at 2.5 mm spacing agree with the Epson drawing. External capacitors remain 10 pF and 18 pF respectively; actual stray capacitance, drive and startup margins require measurement. [Main clock catalog](https://www.lcsc.com/product-detail/C7294624.html), [Epson manufacturer drawing](https://datasheet.lcsc.com/datasheet/pdf/d4d1bd2e87b2e72a8e8e7fe7d590f4c0.pdf?productCode=C32346)

The CPU decoupler rows retain their radial distance from the reference. Extra spacing runs along each edge. Bulk capacitors and crystals/load capacitors have explicit layout overrides to clear imported courtyards and shorten clock connections. These are placement changes; high-frequency return paths remain unrouted.

The pre-route DXIN analysis totals 10.46 mm across its three estimated branches. This is not a routed clock length or a timing pass. The routing-difficulty report flags a region near C23 at an estimated 16% failure probability; this is a solver heuristic, not a measured outcome. Both reports are refreshed for the 112-component stage and retained for later fanout/routing. These checks do not exercise a router.

## What remains

- **R8/R9 are the two remaining reference components**, because neither their values nor the monitored input are defined. The ADC measurement function remains unfinished; it is not designated DNP.
- USB-C power/recovery, the 512 MB SD storage and clock-gated FEL button, boot/ID pulls, and all ten game inputs are connected. [INTERFACE-REVIEW.md](INTERFACE-REVIEW.md) records manufacturer checks, pin mappings and deviations.
- HDMI/audio, a powered controller USB host port, debug header, USB input-current management and firmware are unfinished console functions.
- Exact S4 package/ground-land approval, all voltage limits, sequencing, load budgets, brownout reset, regulator stability, effective decoupling and thermal performance remain open.
- No routed copper, ground planes, fanout result, impedance check or prototype test exists. Netlist agreement and placement DRC cannot prove operating functionality or assembly shorts.

## Reproduce

```sh
# To refresh reference positions, use KiCad's Python with pcbnew:
# <KiCad Python> scripts/extract-s4-placement.py
bun run generate:s4:core
bun run typecheck
bun run audit:s4:imports
bun run check:s4:netlist
bun run check:s4:placement
bun run build:s4:core
bun run audit:s4:core
bun run preview:s4:sheets
```

`audit:s4:core` fails on emitted errors **or warnings**, independently of the CLI exit status. The isolated CPU preview is separately retained as a negative test: `audit:s4:cpu` expects exactly 22 missing-required-connection errors after its build, rather than treating the deliberately unwired fixture as a valid circuit.

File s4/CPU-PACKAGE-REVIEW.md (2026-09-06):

# S4 component using an imported S3 package

On 2026-09-06 the user explicitly authorized reusing the S3 supplier footprint and setting the MPN to **T113M4020DC0 (S4)**. This supersedes the earlier prohibition on S3 package reuse, while preserving the ban on handwritten footprints and on ordering an unintended substitute processor.

## Implemented identity and provenance

| Purpose | Component |
|---|---|
| Geometry, pin labels and 3D model source | T113-S3, JLCPCB C5197687, `imports/T113_S3.tsx` |
| Actual selected processor MPN | **T113M4020DC0** |
| Actual selected JLCPCB ordering number | **C41411351** |
| Component to use in the new circuit | `components/T113M4020DC0.tsx` |

The original import was generated by `tsci import C5197687 --jlcpcb --use-exact-footprint` from `s4/`. It remains byte-for-byte unchanged. The wrapper uses supported component props to override both procurement fields. It does not replace pads, rename pins or manufacture a new footprint. Its public type excludes changes to identity, geometry, pin labels/attributes and the inherited model. The S4 definition itself now assigns required power, ground and internal-LDO roles through supported chip props. The model remains S3-sourced and is not an independently verified S4 mechanical model.

The [Trellis author describes S4 as pin-compatible with S3](https://github.com/protolux-electronics/trellis_core/tree/db4fe71623c14bcea47d7457d0db4c99d3899124). The [S4 supplier listing](https://jlcpcb.com/partdetail/T113M4020DC0/C41411351) specifies eLQFP-128, 14 × 14 mm. These support investigating reuse; they do not substitute for exact S4 package tolerances or electrical specifications.

## Verified checks

- 129 copper pads and numbered ports, including exposed ground pad 129.
- All 129 primary pin labels match the pinned Trellis CPU table by physical pin number after removing the reference's `_number` label suffix. This is reference agreement, not independent S4 datasheet verification.
- Closed imported courtyard contains every pad; no pad bounding boxes overlap. Minimum clearance between pad bounds is 0.199542 mm, and lead pitch is approximately 0.4 mm.
- Compiled package preview retains every imported pad position, shape and dimension and the exact courtyard. Its procurement record contains `T113M4020DC0` / `C41411351`.
- Preview connects AGND 91 and EPAD 129 to GND, leaves NC 106 unconnected, contains no DNP components, copper routes or vias, and uses a schematic sheet and functional section.
- Isolated placement check: zero errors/warnings. This is one package on a 30 × 30 mm inspection board, not a complete console placement test.
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

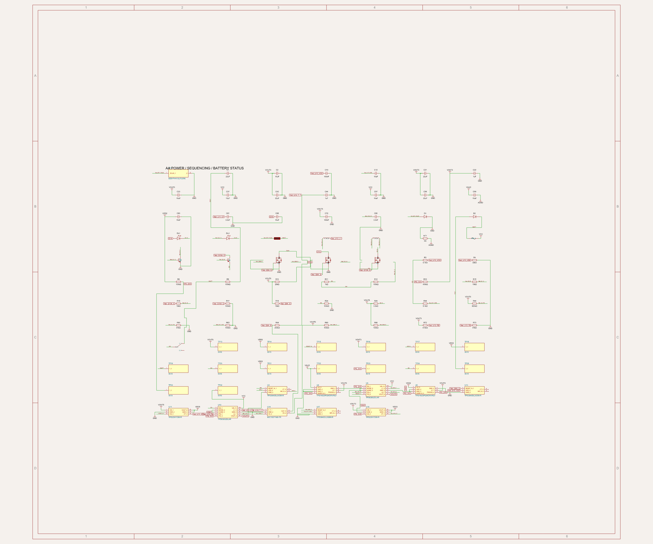
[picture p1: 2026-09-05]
docs/previews/power.png

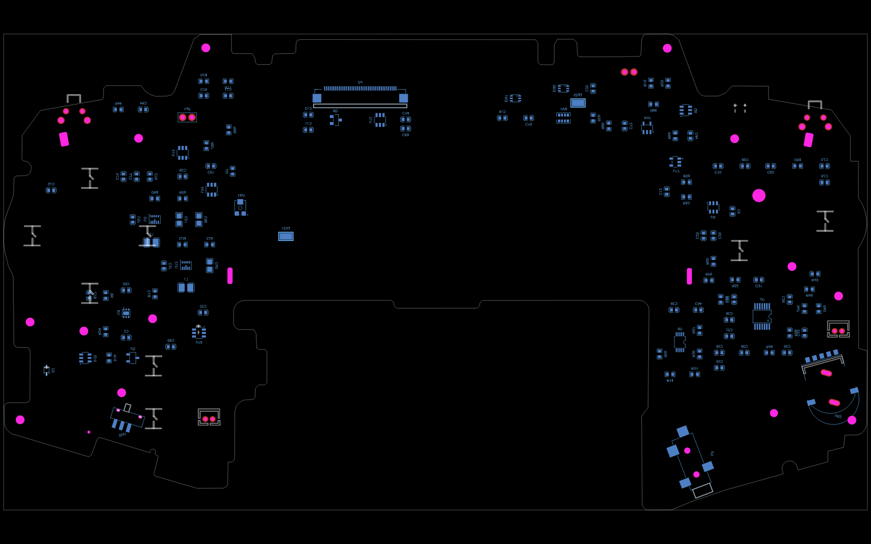
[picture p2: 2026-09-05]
docs/previews/pcb-bottom.png

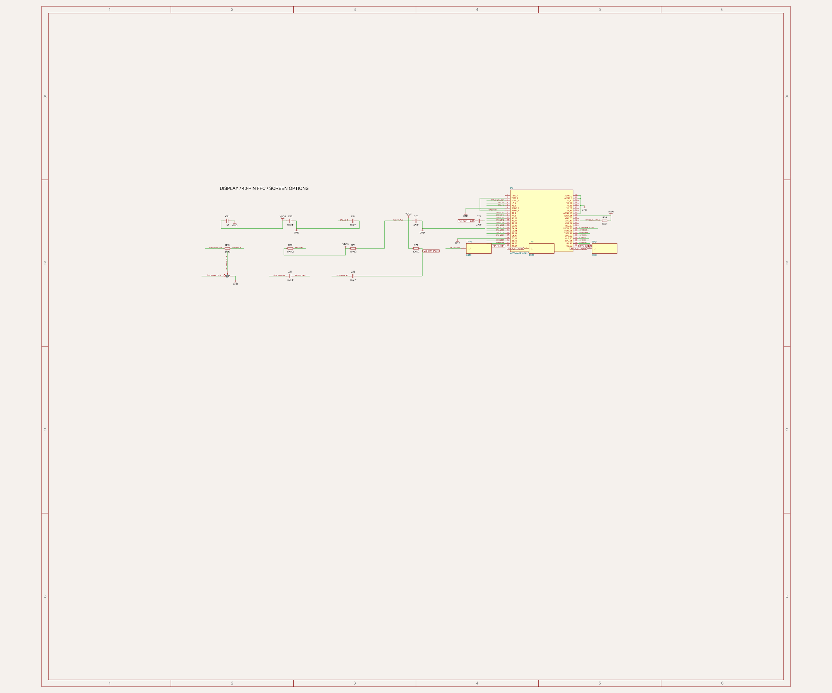
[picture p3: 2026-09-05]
docs/previews/display.png

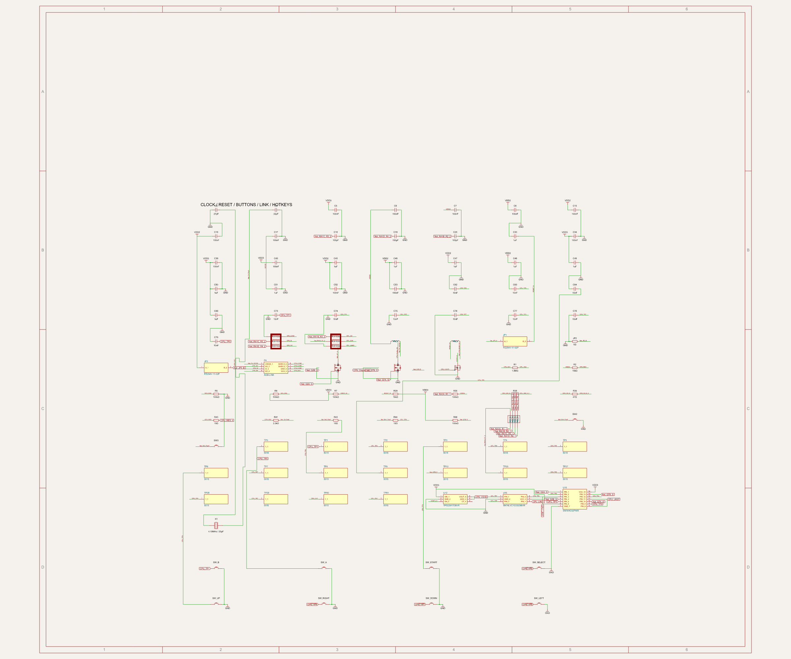
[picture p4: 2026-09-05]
docs/previews/controls.png

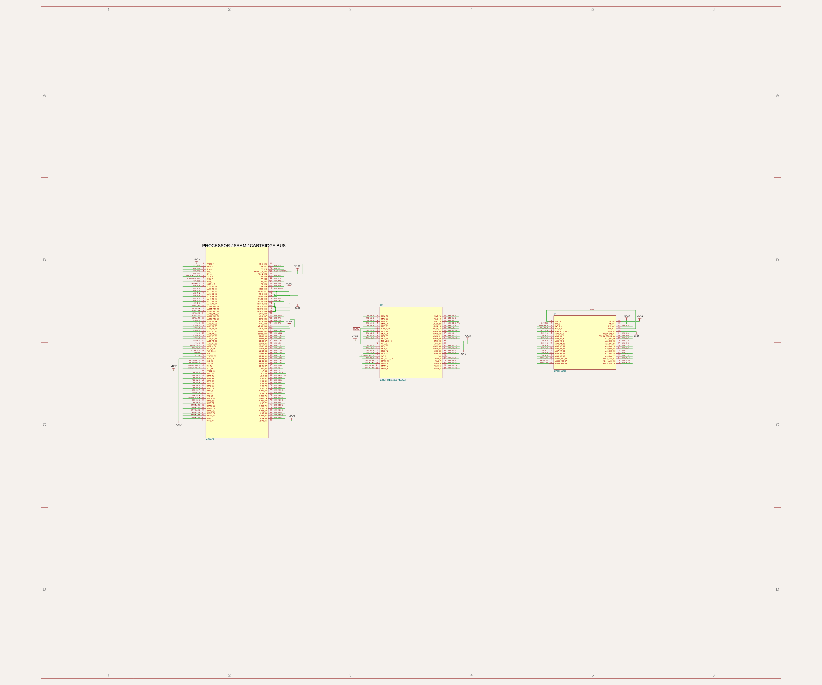
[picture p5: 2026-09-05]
docs/previews/processor.png

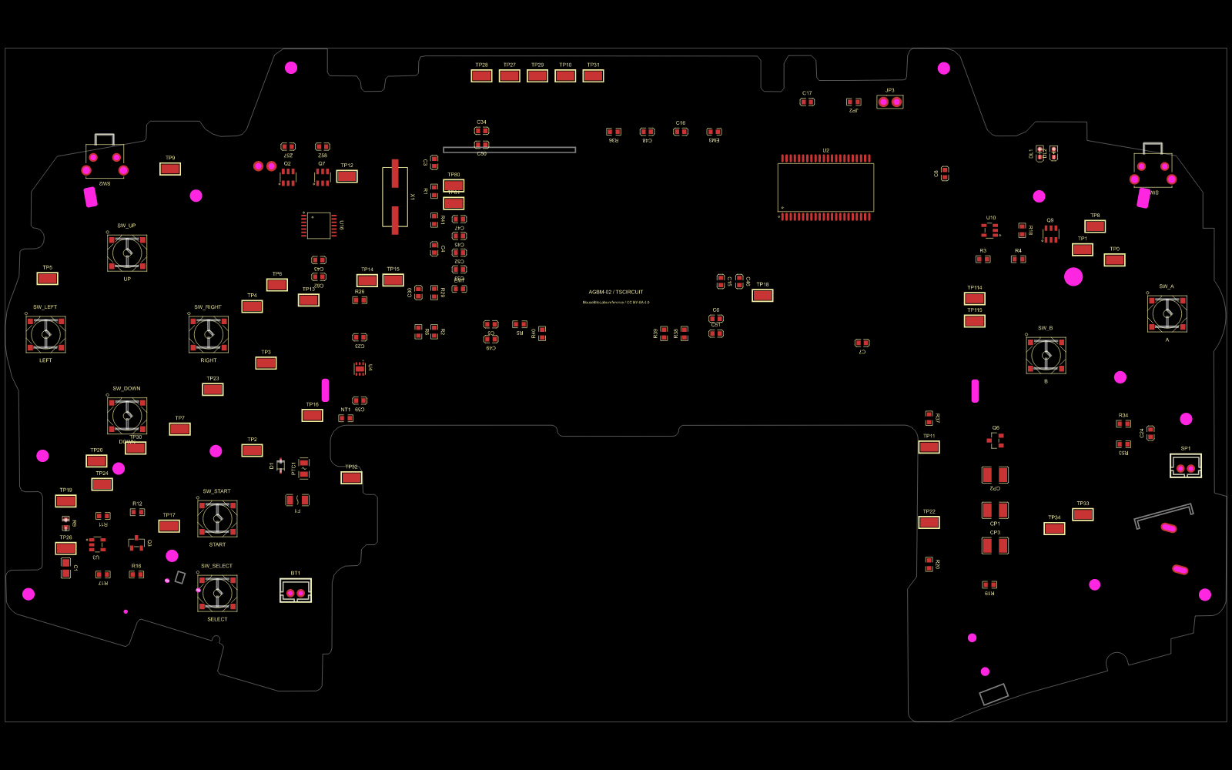
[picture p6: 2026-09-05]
docs/previews/pcb-top.png

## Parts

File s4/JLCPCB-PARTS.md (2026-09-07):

# S4 sourcing and import results

## Current tabletop additions

The active BOM contains 103 parts. All six additions below imported successfully with unchanged supplier geometry/courtyards. No purchase or current assembly-stock guarantee is implied.

| Function | MPN / JLCPCB | Review result |
|---|---|---|
| POWER/RUN | Everlight 19-21SYGC/S530-E2/4T / C2986011 | Electrical symbol polarity corrected against manufacturer drawing; raw footprint unchanged |
| ERROR/USB FAULT | Everlight 19-217/R6C-AL1M2VY/6T / C2986060 | Polarity checked against manufacturer drawing |
| USB power | TI TPS2051BDBVR / C24593 | Pinout reviewed; represented as an electrical chip rather than a mechanical switch |
| Controller connector | 902-131A1011D10100 / C2345 | Standard USB pinout; manufacturer's detailed drawing retrieval blocked |
| Host reservoir | Panasonic EEEFT1A221AP / C401764 | 220 µF/10 V polarized; supplier land-size qualification pending |
| Bias/fault pulls | Yageo RC0603FR-0710KL / C98220 | Existing genuine import reused unchanged; 10 kΩ |

See [console review](CONSOLE-REVIEW.md). The earlier audio-specific notes below are historical; that circuitry is removed from the tabletop scope. The selected S4 still lacks a direct exact import; the authorized S3 geometry remains the explicit sourcing exception. HDMI/ADC selection issues below remain open.

Updated 2026-09-07; earlier catalog stock observations below remain dated 2026-09-06. A catalog listing, successful import and assembly stock are separate checks. Prices/stock can change. Nothing has been ordered. The full, unqualified **reference** BOM is in `reports/reference-bom.csv`; this is not a completed console BOM.

| Function | Exact part / JLCPCB | Found in catalog? | Import / courtyard | Status |
|---|---|---|---|---|
| Selected S4 CPU | [T113M4020DC0 / C41411351](https://jlcpcb.com/partdetail/AllwinnerTech-T113M4020DC0/C41411351) | Yes; also [LCSC](https://www.lcsc.com/product-detail/C41411351.html), which showed 63 units; JLC assembly stock not established | **Direct import failed.** Authorized S3 geometry reused via S4 wrapper; courtyard checked | MPN and ordering identity are S4; physical/electrical qualification pending |
| Alternate combined CPU entry | [T113-S3/S4 / C9900264054](https://jlcpcb.com/partdetail/JLCPCBAssembly-T113_S3S4/C9900264054) | Yes, generic assembly entry; not an exact S4 procurement specification | **Import failed:** Component not found | Not selected |
| CPU geometry source only | T113-S3 / C5197687 | Yes | Exact import successful: 129 pads, closed courtyard, no overlapping pad bounds | User authorized package reuse; S3 is not the ordered processor |
| 3.3 V and core regulators | [TI TLV62569PDDCR / C398365](https://jlcpcb.com/partdetail/TexasInstruments-TLV62569PDDCR/C398365) | Yes | Exact import successful; 6 pads and courtyard checked | Connected in the power/core stage; load/sequencing qualification pending |
| HDMI with audio | [ADI ADV7513BSWZ / C408901](https://jlcpcb.com/partdetail/AnalogDevices-ADV7513BSWZ/C408901) | Yes; CLI search returned 107 units | Exact import successful; 65 pads including ground EP and courtyard checked | Candidate only; circuit, drivers and timing not qualified |
| Alternate DSI bridge | LT8912B / C2892102 (datasheet catalog identifier); C9900039859 assembly entry | Exact CLI name search returned no results; generic assembly listing shows zero stock | Not qualified/imported | Existing T113 software example uses LT8912B, but it is not yet a qualified BOM option |
| Boot storage | Zetta ZDSD04GLGEAG / C2875854 | Found | Exact import successful; 8 pads and courtyard checked | Connected; 512 MB identity/pin map resolved. Pitch, capacitance, timing and boot qualification pending |
| Reference measurement divider | R8/R9 | **No exact components specified:** reference says TODO | No import possible until values selected | Calculate from actual rail and S4 ADC limits |

`tsci search T113-S4 --jlcpcb --json` and `tsci search T113M4020 --jlcpcb --json` returned empty results. This was not treated as proof the part did not exist: the exact MPN/catalog number was subsequently recovered from KiCad and verified on the supplier pages.

The unchanged S3 import is retained as the geometry source. A typed S4 wrapper overrides both manufacturer and supplier ordering identities; C5197687 must not appear as the CPU procurement number in compiled output. No fabricated `@tscircuit/jlcpcb` module is introduced; this installed toolchain uses genuine local files generated by `tsci import --jlcpcb --use-exact-footprint`.

## Power/core import update

All 16 additional reference power, decoupling, reset and clock part numbers imported successfully. `reports/power-core-imports.json` records each exact command result. All 41 available candidate packages have courtyards and pass geometry checks. The connected stage BOM is `reports/power-core-bom.csv`; it identifies assembly parts without claiming complete electrical qualification. R8/R9 still lack selected values/MPNs. USB-C, storage, the powered USB1 controller port and indicators are now connected. Onboard game inputs and analog audio belong to the historical handheld revision. HDMI video/audio and debug circuitry remain unfinished.

## Interface imports added

All six were generated by `tsci import <part-number> --jlcpcb --use-exact-footprint`; supplier land patterns are unchanged. These are successful imports, not an assertion of current assembly stock.

| Part | JLCPCB | Function | Import geometry |
|---|---|---|---|
| ZDSD04GLGEAG | C2875854 | 512 MB SD storage | 8 pads, closed courtyard; pitch qualification open |
| HX-TYPE-C-16P-L8.35 | C41427493 | USB-C power/recovery | 16 numbered pads including shell stakes, 2 nonplated holes, courtyard |
| TI SN74AHC1G08DCKR | C122838 | Storage clock / FEL gate | 5 pads, courtyard |
| ST USBLC6-2SC6 | C2827654 | USB data ESD protection | 6 pads, courtyard |
| JK-nSMD100-16 | C369161 | Input PTC | 2 pads, courtyard |
| 0402WGF220JTCE | C25092 | 22 Ω clock series resistor | 2 pads, courtyard |

The ten game inputs reuse three existing imports (switch, 5.1 kΩ resistor and 100 nF capacitor). Complete connected procurement rows are in `reports/power-core-bom.csv`. S4 CPU direct import and exact unselected ADC parts remain the explicit sourcing issues; no substitute footprint has been invented.

## Retained audio imports

These existing CLI-generated JLCPCB imports are reused unchanged, including courtyards. Import success does not establish present assembly stock or electrical qualification.

| MPN | JLCPCB | Status |
|---|---|---|
| 0603WAF1001T5E | C21190 | Imported unchanged; electrical qualification pending |
| 0603WAF2002T5E | C4184 | Imported unchanged; electrical qualification pending |
| B2B-PH-K-S(LF)(SN) | C131337 | Imported unchanged; electrical qualification pending |
| CL10B105KA8NNNC | C29936 | Imported unchanged; electrical qualification pending |
| CL32A107MQVNNNE | C49066 | Imported unchanged; electrical qualification pending |
| LM4853MM/NOPB | C2872995 | Imported unchanged; electrical qualification pending |
| MMBT3904LT1G | C81464 | Imported unchanged; electrical qualification pending |
| RK10J12R0A0B | C351175 | Imported; repeated mounting pads and passive dual-gang representation block acceptance |
| SJ-3524-SMT-TR | C20182907 | Imported unchanged; electrical qualification pending |
| TPS74525PQWDRVRQ1 | C2865628 | Imported unchanged; electrical qualification pending |

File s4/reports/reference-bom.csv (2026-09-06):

reference | symbol_value | manufacturer_part_number | jlcpcb_part_number | reference_sheet | import_status
C1 | 10u | CL10A106MA8NRNC | C96446 | /Architecture/Power/ | not_qualified
C2 | 10p | CL05C100JB5NNNC | C32949 | /Architecture/Power/ | not_qualified
C3 | 10u | CL10A106MA8NRNC | C96446 | /Architecture/Power/ | not_qualified
C4 | 10p | CL05C100JB5NNNC | C32949 | /Architecture/Power/ | not_qualified
C5 | 22u | CL21A226MAQNNNE | C45783 | /Architecture/Power/ | not_qualified
C6 | 22u | CL21A226MAQNNNE | C45783 | /Architecture/Power/ | not_qualified
C7 | 10u | CL10A106MA8NRNC | C96446 | /Architecture/Power/ | not_qualified
C8 | 100n | CL05B104KB54PNC | C307331 | /Architecture/Power/ | not_qualified
D1 | RED | NCD0805R1 | C84256 | /Architecture/Power/ | not_qualified
L1 | 2u2 | XRIM252012S2R2MBCA | C22471111 | /Architecture/Power/ | not_qualified
L2 | 2u2 | XRIM252012S2R2MBCA | C22471111 | /Architecture/Power/ | not_qualified
R1 | 100k | 0402WGF1003TCE | C25741 | /Architecture/Power/ | not_qualified
R2 | 453k | 0402WGF4533TCE | C27009 | /Architecture/Power/ | not_qualified
R3 | 100k | 0402WGF1003TCE | C25741 | /Architecture/Power/ | not_qualified
R4 | 5k1 | 0402WGF5101TCE | C25905 | /Architecture/Power/ | not_qualified
R5 | 51k | 0402WGF5102TCE | C25794 | /Architecture/Power/ | not_qualified
R6 | 100k | 0402WGF1003TCE | C25741 | /Architecture/Power/ | not_qualified
R7 | 100k | 0402WGF1003TCE | C25741 | /Architecture/Power/ | not_qualified
U1 | TLV62569PDDCR | TLV62569PDDCR | C398365 | /Architecture/Power/ | not_qualified
U2 | TLV62569PDDCR | TLV62569PDDCR | C398365 | /Architecture/Power/ | not_qualified
C9 | 2u2 | CL05A225MQ5NSNC | C12530 | /Architecture/CPU Core/ | not_qualified
C10 | 10u | CL10A106MA8NRNC | C96446 | /Architecture/CPU Core/ | not_qualified
C11 | 100n | CL05B104KB54PNC | C307331 | /Architecture/CPU Core/ | not_qualified
C12 | 100n | CL05B104KB54PNC | C307331 | /Architecture/CPU Core/ | not_qualified
C13 | 100n | CL05B104KB54PNC | C307331 | /Architecture/CPU Core/ | not_qualified
C14 | 100n | CL05B104KB54PNC | C307331 | /Architecture/CPU Core/ | not_qualified
C15 | 100n | CL05B104KB54PNC | C307331 | /Architecture/CPU Core/ | not_qualified
C16 | 2u2 | CL05A225MQ5NSNC | C12530 | /Architecture/CPU Core/ | not_qualified
C17 | 100n | CL05B104KB54PNC | C307331 | /Architecture/CPU Core/ | not_qualified
C18 | 100n | CL05B104KB54PNC | C307331 | /Architecture/CPU Core/ | not_qualified
C19 | 100n | CL05B104KB54PNC | C307331 | /Architecture/CPU Core/ | not_qualified
C20 | 100n | CL05B104KB54PNC | C307331 | /Architecture/CPU Core/ | not_qualified
C21 | 100n | CL05B104KB54PNC | C307331 | /Architecture/CPU Core/ | not_qualified
C22 | 10u | CL10A106MA8NRNC | C96446 | /Architecture/CPU Core/ | not_qualified
C23 | 100n | CL05B104KB54PNC | C307331 | /Architecture/CPU Core/ | not_qualified
C24 | 100n | CL05B104KB54PNC | C307331 | /Architecture/CPU Core/ | not_qualified
C25 | 100n | CL05B104KB54PNC | C307331 | /Architecture/CPU Core/ | not_qualified
C26 | 100n | CL05B104KB54PNC | C307331 | /Architecture/CPU Core/ | not_qualified
C27 | 100n | CL05B104KB54PNC | C307331 | /Architecture/CPU Core/ | not_qualified
C28 | 2u2 | CL05A225MQ5NSNC | C12530 | /Architecture/CPU Core/ | not_qualified
C29 | 10u | CL10A106MA8NRNC | C96446 | /Architecture/CPU Core/ | not_qualified
C30 | 100n | CL05B104KB54PNC | C307331 | /Architecture/CPU Core/ | not_qualified
C31 | 100n | CL05B104KB54PNC | C307331 | /Architecture/CPU Core/ | not_qualified
C32 | 10p | CL05C100JB5NNNC | C32949 | /Architecture/CPU Core/ | not_qualified
C33 | 10p | CL05C100JB5NNNC | C32949 | /Architecture/CPU Core/ | not_qualified
C34 | 100n | CL05B104KB54PNC | C307331 | /Architecture/CPU Core/ | not_qualified
C35 | 100n | CL05B104KB54PNC | C307331 | /Architecture/CPU Core/ | not_qualified
C36 | 18p | 0402CG180J500NT | C1549 | /Architecture/CPU Core/ | not_qualified
C37 | 18p | 0402CG180J500NT | C1549 | /Architecture/CPU Core/ | not_qualified
C38 | 100n | CL05B104KB54PNC | C307331 | /Architecture/CPU Core/ | not_qualified
C39 | 100n | CL05B104KB54PNC | C307331 | /Architecture/CPU Core/ | not_qualified
C40 | 2u2 | CL05A225MQ5NSNC | C12530 | /Architecture/CPU Core/ | not_qualified
R8 | TODO |  |  | /Architecture/CPU Core/ | not_qualified
R9 | TODO |  |  | /Architecture/CPU Core/ | not_qualified
R10 | 240R | 0603WAF2400T5E | C23350 | /Architecture/CPU Core/ | not_qualified
R11 | 100k | 0402WGF1003TCE | C25741 | /Architecture/CPU Core/ | not_qualified
SW1 | SW_Push | TSA010A2026B | C2888420 | /Architecture/CPU Core/ | not_qualified
U3 | T113-S3 | T113M4020DC0 | C41411351 | /Architecture/CPU Core/ | not_qualified
Y1 | 24MHz | CM4024M00008001 | C7294624 | /Architecture/CPU Core/ | not_qualified
Y2 | 32.768kHz | Q13FC13500004 | C32346 | /Architecture/CPU Core/ | not_qualified
R12 | 5k1 | 0402WGF5101TCE | C25905 | /Architecture/CPU IO/ | not_qualified
R13 | 5k1 | 0402WGF5101TCE | C25905 | /Architecture/CPU IO/ | not_qualified
R14 | 5k1 | 0402WGF5101TCE | C25905 | /Architecture/CPU IO/ | not_qualified
R24 | 5k1 | 0402WGF5101TCE | C25905 | /Architecture/CPU IO/ | not_qualified
R25 | 5k1 | 0402WGF5101TCE | C25905 | /Architecture/CPU IO/ | not_qualified
F1 | 1A | JK-nSMD100-16 | C369161 | /Architecture/USB/ | not_qualified
J1 | USB_C_Receptacle_USB2.0_14P | HX TYPE-C 16P L8.35 | C41427493 | /Architecture/USB/ | not_qualified
R15 | 5k1 | 0402WGF5101TCE | C25905 | /Architecture/USB/ | not_qualified
R16 | 5k1 | 0402WGF5101TCE | C25905 | /Architecture/USB/ | not_qualified
U4 | USBLC6-2SC6 | USBLC6-2SC6 | C2827654 | /Architecture/USB/ | not_qualified
C41 | 10u | CL10A106MA8NRNC | C96446 | /Architecture/Storage/ | not_qualified
C42 | 100n | CL05B104KB54PNC | C307331 | /Architecture/Storage/ | not_qualified
C43 | 100n | CL05B104KB54PNC | C307331 | /Architecture/Storage/ | not_qualified
C44 | 100n | CL05B104KB54PNC | C307331 | /Architecture/Storage/ | not_qualified
R17 | 51k | 0402WGF5102TCE | C25794 | /Architecture/Storage/ | not_qualified
R18 | 51k | 0402WGF5102TCE | C25794 | /Architecture/Storage/ | not_qualified
R19 | 51k | 0402WGF5102TCE | C25794 | /Architecture/Storage/ | not_qualified
R20 | 51k | 0402WGF5102TCE | C25794 | /Architecture/Storage/ | not_qualified
R21 | 51k | 0402WGF5102TCE | C25794 | /Architecture/Storage/ | not_qualified
R22 | 5k1 | 0402WGF5101TCE | C25905 | /Architecture/Storage/ | not_qualified
R23 | 22R | 0402WGF220JTCE | C25092 | /Architecture/Storage/ | not_qualified
SW2 | SW_Push | TSA010A2026B | C2888420 | /Architecture/Storage/ | not_qualified
U5 | ZDSD08GLGEAG | ZDSD04GLGEAG | C2875854 | /Architecture/Storage/ | not_qualified
U6 | SN74AHC1G08 | SN74AHC1G08DCKR | C122838 | /Architecture/Storage/ | not_qualified

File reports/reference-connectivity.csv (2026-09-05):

reference | original_pin | original_net | physical_endpoint | status
P1 | 6 | /CPU/A_{0} | P1.pin6 | reference-connectivity-only
U1 | 33 | /CPU/A_{0} | U1.pin33 | reference-connectivity-only
P1 | 7 | /CPU/A_{1} | P1.pin7 | reference-connectivity-only
U1 | 32 | /CPU/A_{1} | U1.pin32 | reference-connectivity-only
P1 | 8 | /CPU/A_{2} | P1.pin8 | reference-connectivity-only
U1 | 31 | /CPU/A_{2} | U1.pin31 | reference-connectivity-only
P1 | 9 | /CPU/A_{3} | P1.pin9 | reference-connectivity-only
U1 | 30 | /CPU/A_{3} | U1.pin30 | reference-connectivity-only
P1 | 10 | /CPU/A_{4} | P1.pin10 | reference-connectivity-only
U1 | 29 | /CPU/A_{4} | U1.pin29 | reference-connectivity-only
P1 | 11 | /CPU/A_{5} | P1.pin11 | reference-connectivity-only
U1 | 28 | /CPU/A_{5} | U1.pin28 | reference-connectivity-only
P1 | 12 | /CPU/A_{6} | P1.pin12 | reference-connectivity-only
U1 | 27 | /CPU/A_{6} | U1.pin27 | reference-connectivity-only
P1 | 13 | /CPU/A_{7} | P1.pin13 | reference-connectivity-only
U1 | 26 | /CPU/A_{7} | U1.pin26 | reference-connectivity-only
P1 | 14 | /CPU/A_{8} | P1.pin14 | reference-connectivity-only
U1 | 25 | /CPU/A_{8} | U1.pin25 | reference-connectivity-only
P1 | 15 | /CPU/A_{9} | P1.pin15 | reference-connectivity-only
U1 | 24 | /CPU/A_{9} | U1.pin24 | reference-connectivity-only
P1 | 16 | /CPU/A_{10} | P1.pin16 | reference-connectivity-only
U1 | 23 | /CPU/A_{10} | U1.pin23 | reference-connectivity-only
P1 | 17 | /CPU/A_{11} | P1.pin17 | reference-connectivity-only
U1 | 22 | /CPU/A_{11} | U1.pin22 | reference-connectivity-only
P1 | 18 | /CPU/A_{12} | P1.pin18 | reference-connectivity-only
U1 | 21 | /CPU/A_{12} | U1.pin21 | reference-connectivity-only
P1 | 19 | /CPU/A_{13} | P1.pin19 | reference-connectivity-only
U1 | 20 | /CPU/A_{13} | U1.pin20 | reference-connectivity-only
P1 | 20 | /CPU/A_{14} | P1.pin20 | reference-connectivity-only
U1 | 19 | /CPU/A_{14} | U1.pin19 | reference-connectivity-only
P1 | 21 | /CPU/A_{15} | P1.pin21 | reference-connectivity-only
U1 | 18 | /CPU/A_{15} | U1.pin18 | reference-connectivity-only
TP115 | 1 | /CPU/Audio/L-OUT | TP115.pin1 | reference-connectivity-only
U1 | 7 | /CPU/Audio/L-OUT | U1.pin7 | reference-connectivity-only
U9 | 1 | /CPU/Audio/L-OUT | U9.pin1 | reference-connectivity-only
C56 | 1 | /CPU/Audio/LIN | C56.pin1 | reference-connectivity-only
TP33 | 1 | /CPU/Audio/LIN | TP33.pin1 | reference-connectivity-only
VR2 | 3 | /CPU/Audio/LIN | VR2.pin3 | reference-connectivity-only
TP114 | 1 | /CPU/Audio/R-OUT | TP114.pin1 | reference-connectivity-only
U1 | 6 | /CPU/Audio/R-OUT | U1.pin6 | reference-connectivity-only
U9 | 3 | /CPU/Audio/R-OUT | U9.pin3 | reference-connectivity-only
C55 | 1 | /CPU/Audio/RIN | C55.pin1 | reference-connectivity-only
TP34 | 1 | /CPU/Audio/RIN | TP34.pin1 | reference-connectivity-only
VR2 | 4 | /CPU/Audio/RIN | VR2.pin5 | reference-connectivity-only
C3 | 2 | /CPU/CK1 | C3.pin2 | reference-connectivity-only
R1 | 1 | /CPU/CK1 | R1.pin1 | reference-connectivity-only
TP80 | 1 | /CPU/CK1 | TP80.pin1 | reference-connectivity-only
U1 | 113 | /CPU/CK1 | U1.pin113 | reference-connectivity-only
X1 | 1 | /CPU/CK1 | X1.pin1 | reference-connectivity-only
R1 | 2 | /CPU/CK2 | R1.pin2 | reference-connectivity-only
R41 | 1 | /CPU/CK2 | R41.pin1 | reference-connectivity-only
TP81 | 1 | /CPU/CK2 | TP81.pin1 | reference-connectivity-only
U1 | 114 | /CPU/CK2 | U1.pin114 | reference-connectivity-only
P2 | 25 | /CPU/CLS | P2.pin25 | reference-connectivity-only
U1 | 105 | /CPU/CLS | U1.pin105 | reference-connectivity-only
R36 | 2 | /CPU/DCK_{R} | R36.pin2 | reference-connectivity-only
U1 | 84 | /CPU/DCK_{R} | U1.pin84 | reference-connectivity-only
P1 | 22 | /CPU/D_{0} | P1.pin22 | reference-connectivity-only
U1 | 17 | /CPU/D_{0} | U1.pin17 | reference-connectivity-only
P1 | 23 | /CPU/D_{1} | P1.pin23 | reference-connectivity-only
U1 | 16 | /CPU/D_{1} | U1.pin16 | reference-connectivity-only
P1 | 24 | /CPU/D_{2} | P1.pin24 | reference-connectivity-only
U1 | 15 | /CPU/D_{2} | U1.pin15 | reference-connectivity-only
P1 | 25 | /CPU/D_{3} | P1.pin25 | reference-connectivity-only
U1 | 14 | /CPU/D_{3} | U1.pin14 | reference-connectivity-only
P1 | 26 | /CPU/D_{4} | P1.pin26 | reference-connectivity-only
U1 | 13 | /CPU/D_{4} | U1.pin13 | reference-connectivity-only
P1 | 27 | /CPU/D_{5} | P1.pin27 | reference-connectivity-only
U1 | 12 | /CPU/D_{5} | U1.pin12 | reference-connectivity-only
P1 | 28 | /CPU/D_{6} | P1.pin28 | reference-connectivity-only
U1 | 11 | /CPU/D_{6} | U1.pin11 | reference-connectivity-only
P1 | 29 | /CPU/D_{7} | P1.pin29 | reference-connectivity-only
U1 | 10 | /CPU/D_{7} | U1.pin10 | reference-connectivity-only
P2 | 3 | /CPU/Display/DCK | P2.pin3 | reference-connectivity-only
R36 | 1 | /CPU/Display/DCK | R36.pin1 | reference-connectivity-only
P2 | 29 | /CPU/Display/VCOM | P2.pin29 | reference-connectivity-only
VR1 | 2 | /CPU/Display/VCOM | VR1.pin2 | reference-connectivity-only
R26 | 1 | /CPU/Display/VR1-2 | R26.pin1 | reference-connectivity-only
VR1 | 1 | /CPU/Display/VR1-2 | VR1.pin1 | reference-connectivity-only
Q7 | 6 | /CPU/Display/ZA | Q7.pin6 | reference-connectivity-only
Z58 | 1 | /CPU/Display/ZA | Z58.pin1 | reference-connectivity-only
Q2 | 4 | /CPU/Display/ZB | Q2.pin4 | reference-connectivity-only
Z57 | 1 | /CPU/Display/ZB | Z57.pin1 | reference-connectivity-only
P1 | C2 | /CPU/IN35 | P1.pin34 | reference-connectivity-only
R5 | 1 | /CPU/IN35 | R5.pin1 | reference-connectivity-only
U1 | 2 | /CPU/IN35 | U1.pin2 | reference-connectivity-only
P1 | 31 | /CPU/IRQ | P1.pin31 | reference-connectivity-only
R6 | 2 | /CPU/IRQ | R6.pin2 | reference-connectivity-only
U1 | 8 | /CPU/IRQ | U1.pin8 | reference-connectivity-only
P2 | 23 | /CPU/LDB1 | P2.pin23 | reference-connectivity-only
U1 | 101 | /CPU/LDB1 | U1.pin101 | reference-connectivity-only
P2 | 22 | /CPU/LDB2 | P2.pin22 | reference-connectivity-only
U1 | 100 | /CPU/LDB2 | U1.pin100 | reference-connectivity-only
P2 | 21 | /CPU/LDB3 | P2.pin21 | reference-connectivity-only
U1 | 99 | /CPU/LDB3 | U1.pin99 | reference-connectivity-only
P2 | 20 | /CPU/LDB4 | P2.pin20 | reference-connectivity-only
U1 | 98 | /CPU/LDB4 | U1.pin98 | reference-connectivity-only
P2 | 19 | /CPU/LDB5 | P2.pin19 | reference-connectivity-only
U1 | 97 | /CPU/LDB5 | U1.pin97 | reference-connectivity-only
P2 | 17 | /CPU/LDG1 | P2.pin17 | reference-connectivity-only
U1 | 96 | /CPU/LDG1 | U1.pin96 | reference-connectivity-only
P2 | 16 | /CPU/LDG2 | P2.pin16 | reference-connectivity-only
U1 | 95 | /CPU/LDG2 | U1.pin95 | reference-connectivity-only
P2 | 15 | /CPU/LDG3 | P2.pin15 | reference-connectivity-only
U1 | 94 | /CPU/LDG3 | U1.pin94 | reference-connectivity-only
P2 | 14 | /CPU/LDG4 | P2.pin14 | reference-connectivity-only
U1 | 93 | /CPU/LDG4 | U1.pin93 | reference-connectivity-only
P2 | 13 | /CPU/LDG5 | P2.pin13 | reference-connectivity-only
U1 | 92 | /CPU/LDG5 | U1.pin92 | reference-connectivity-only
P2 | 12 | /CPU/LDR1 | P2.pin12 | reference-connectivity-only
U1 | 91 | /CPU/LDR1 | U1.pin91 | reference-connectivity-only
P2 | 11 | /CPU/LDR2 | P2.pin11 | reference-connectivity-only
U1 | 90 | /CPU/LDR2 | U1.pin90 | reference-connectivity-only
P2 | 10 | /CPU/LDR3 | P2.pin10 | reference-connectivity-only
U1 | 89 | /CPU/LDR3 | U1.pin89 | reference-connectivity-only
P2 | 9 | /CPU/LDR4 | P2.pin9 | reference-connectivity-only
U1 | 88 | /CPU/LDR4 | U1.pin88 | reference-connectivity-only
P2 | 8 | /CPU/LDR5 | P2.pin8 | reference-connectivity-only
U1 | 87 | /CPU/LDR5 | U1.pin87 | reference-connectivity-only
EM1 | 6 | /CPU/LGND | EM1.pin6 | reference-connectivity-only
EM2 | 4 | /CPU/LGND | EM2.pin4 | reference-connectivity-only
P4 | 6 | /CPU/LGND | P4.pin6 | reference-connectivity-only
P4 | 7 | /CPU/LGND | P4.pin7 | reference-connectivity-only
P4 | 8 | /CPU/LGND | P4.pin8 | reference-connectivity-only
P2 | 4 | /CPU/LP | P2.pin4 | reference-connectivity-only
U1 | 85 | /CPU/LP | U1.pin85 | reference-connectivity-only
U15 | 4 | /CPU/LRST | U15.pin4 | reference-connectivity-only
U16 | 11 | /CPU/LRST | U16.pin11 | reference-connectivity-only
U16 | 3 | /CPU/LRST | U16.pin3 | reference-connectivity-only
U16 | 6 | /CPU/LRST | U16.pin6 | reference-connectivity-only
U16 | 8 | /CPU/LRST | U16.pin8 | reference-connectivity-only
U1 | 45 | /CPU/MA_{0} | U1.pin45 | reference-connectivity-only
U2 | 25 | /CPU/MA_{0} | U2.pin5 | reference-connectivity-only
U1 | 46 | /CPU/MA_{1} | U1.pin46 | reference-connectivity-only
U2 | 24 | /CPU/MA_{1} | U2.pin4 | reference-connectivity-only
U1 | 47 | /CPU/MA_{2} | U1.pin47 | reference-connectivity-only
U2 | 23 | /CPU/MA_{2} | U2.pin3 | reference-connectivity-only
U1 | 48 | /CPU/MA_{3} | U1.pin48 | reference-connectivity-only
U2 | 22 | /CPU/MA_{3} | U2.pin2 | reference-connectivity-only
U1 | 49 | /CPU/MA_{4} | U1.pin49 | reference-connectivity-only
U2 | 21 | /CPU/MA_{4} | U2.pin1 | reference-connectivity-only
U1 | 50 | /CPU/MA_{5} | U1.pin50 | reference-connectivity-only
U2 | 20 | /CPU/MA_{5} | U2.pin44 | reference-connectivity-only
U1 | 51 | /CPU/MA_{6} | U1.pin51 | reference-connectivity-only
U2 | 19 | /CPU/MA_{6} | U2.pin43 | reference-connectivity-only
U1 | 52 | /CPU/MA_{7} | U1.pin52 | reference-connectivity-only
U2 | 18 | /CPU/MA_{7} | U2.pin42 | reference-connectivity-only
U1 | 56 | /CPU/MA_{8} | U1.pin56 | reference-connectivity-only
U2 | 8 | /CPU/MA_{8} | U2.pin27 | reference-connectivity-only
U1 | 57 | /CPU/MA_{9} | U1.pin57 | reference-connectivity-only
U2 | 7 | /CPU/MA_{9} | U2.pin26 | reference-connectivity-only
U1 | 58 | /CPU/MA_{10} | U1.pin58 | reference-connectivity-only
U2 | 6 | /CPU/MA_{10} | U2.pin25 | reference-connectivity-only
U1 | 59 | /CPU/MA_{11} | U1.pin59 | reference-connectivity-only
U2 | 5 | /CPU/MA_{11} | U2.pin24 | reference-connectivity-only
U1 | 60 | /CPU/MA_{12} | U1.pin60 | reference-connectivity-only
U2 | 4 | /CPU/MA_{12} | U2.pin23 | reference-connectivity-only
U1 | 61 | /CPU/MA_{13} | U1.pin61 | reference-connectivity-only
U2 | 3 | /CPU/MA_{13} | U2.pin22 | reference-connectivity-only
U1 | 62 | /CPU/MA_{14} | U1.pin62 | reference-connectivity-only
U2 | 2 | /CPU/MA_{14} | U2.pin21 | reference-connectivity-only
U1 | 63 | /CPU/MA_{15} | U1.pin63 | reference-connectivity-only
U2 | 1 | /CPU/MA_{15} | U2.pin20 | reference-connectivity-only
U1 | 74 | /CPU/MA_{16} | U1.pin74 | reference-connectivity-only
U2 | 48 | /CPU/MA_{16} | U2.pin19 | reference-connectivity-only
U1 | 82 | /CPU/MD_{0} | U1.pin82 | reference-connectivity-only
U2 | 29 | /CPU/MD_{0} | U2.pin7 | reference-connectivity-only
U1 | 80 | /CPU/MD_{1} | U1.pin80 | reference-connectivity-only
U2 | 31 | /CPU/MD_{1} | U2.pin8 | reference-connectivity-only
U1 | 78 | /CPU/MD_{2} | U1.pin78 | reference-connectivity-only
U2 | 33 | /CPU/MD_{2} | U2.pin9 | reference-connectivity-only
U1 | 76 | /CPU/MD_{3} | U1.pin76 | reference-connectivity-only
U2 | 35 | /CPU/MD_{3} | U2.pin10 | reference-connectivity-only
U1 | 66 | /CPU/MD_{4} | U1.pin66 | reference-connectivity-only
U2 | 38 | /CPU/MD_{4} | U2.pin13 | reference-connectivity-only
U1 | 68 | /CPU/MD_{5} | U1.pin68 | reference-connectivity-only
U2 | 40 | /CPU/MD_{5} | U2.pin14 | reference-connectivity-only
U1 | 70 | /CPU/MD_{6} | U1.pin70 | reference-connectivity-only
U2 | 42 | /CPU/MD_{6} | U2.pin15 | reference-connectivity-only
U1 | 72 | /CPU/MD_{7} | U1.pin72 | reference-connectivity-only
U2 | 44 | /CPU/MD_{7} | U2.pin16 | reference-connectivity-only
U1 | 81 | /CPU/MD_{8} | U1.pin81 | reference-connectivity-only
U2 | 30 | /CPU/MD_{8} | U2.pin29 | reference-connectivity-only
U1 | 79 | /CPU/MD_{9} | U1.pin79 | reference-connectivity-only
U2 | 32 | /CPU/MD_{9} | U2.pin30 | reference-connectivity-only
U1 | 77 | /CPU/MD_{10} | U1.pin77 | reference-connectivity-only
U2 | 34 | /CPU/MD_{10} | U2.pin31 | reference-connectivity-only
U1 | 75 | /CPU/MD_{11} | U1.pin75 | reference-connectivity-only
U2 | 36 | /CPU/MD_{11} | U2.pin32 | reference-connectivity-only
U1 | 67 | /CPU/MD_{12} | U1.pin67 | reference-connectivity-only
U2 | 39 | /CPU/MD_{12} | U2.pin35 | reference-connectivity-only
U1 | 69 | /CPU/MD_{13} | U1.pin69 | reference-connectivity-only
U2 | 41 | /CPU/MD_{13} | U2.pin36 | reference-connectivity-only
U1 | 71 | /CPU/MD_{14} | U1.pin71 | reference-connectivity-only
U2 | 43 | /CPU/MD_{14} | U2.pin37 | reference-connectivity-only
U1 | 73 | /CPU/MD_{15} | U1.pin73 | reference-connectivity-only
U2 | 45 | /CPU/MD_{15} | U2.pin38 | reference-connectivity-only
P2 | 28 | /CPU/MOD | P2.pin28 | reference-connectivity-only
U1 | 107 | /CPU/MOD | U1.pin107 | reference-connectivity-only
P1 | 2 | /CPU/PHI | P1.pin2 | reference-connectivity-only
U1 | 37 | /CPU/PHI | U1.pin37 | reference-connectivity-only
P2 | 5 | /CPU/PS | P2.pin5 | reference-connectivity-only
U1 | 86 | /CPU/PS | U1.pin86 | reference-connectivity-only
P1 | 30 | /CPU/RES | P1.pin30 | reference-connectivity-only
R2 | 2 | /CPU/RES | R2.pin2 | reference-connectivity-only
R40 | 1 | /CPU/RES | R40.pin1 | reference-connectivity-only
R40 | 2 | /CPU/RES_{0} | R40.pin2 | reference-connectivity-only
U1 | 9 | /CPU/RES_{0} | U1.pin9 | reference-connectivity-only
EM2 | 5 | /CPU/SCK | EM2.pin5 | reference-connectivity-only
P4 | 5 | /CPU/SCK | P4.pin5 | reference-connectivity-only
EM2 | 6 | /CPU/SD | EM2.pin6 | reference-connectivity-only
P4 | 4 | /CPU/SD | P4.pin4 | reference-connectivity-only
EM1 | 5 | /CPU/SI | EM1.pin5 | reference-connectivity-only
P4 | 3 | /CPU/SI | P4.pin3 | reference-connectivity-only
EM1 | 4 | /CPU/SO | EM1.pin4 | reference-connectivity-only
P4 | 2 | /CPU/SO | P4.pin2 | reference-connectivity-only
P2 | 24 | /CPU/SPL | P2.pin24 | reference-connectivity-only
U1 | 104 | /CPU/SPL | U1.pin104 | reference-connectivity-only
P2 | 26 | /CPU/SPS | P2.pin26 | reference-connectivity-only
U1 | 106 | /CPU/SPS | U1.pin106 | reference-connectivity-only
C79 | 2 | /CPU/TP0 | C79.pin2 | reference-connectivity-only
SW4 | 2 | /CPU/TP0 | SW_A.pin1 | reference-connectivity-only
SW4 | 2 | /CPU/TP0 | SW_A.pin3 | reference-connectivity-only
TP0 | 1 | /CPU/TP0 | TP0.pin1 | reference-connectivity-only
U1 | 4 | /CPU/TP0 | U1.pin4 | reference-connectivity-only
U16 | 9 | /CPU/TP0 | U16.pin9 | reference-connectivity-only
C73 | 2 | /CPU/TP1 | C73.pin2 | reference-connectivity-only
SW4 | 1 | /CPU/TP1 | SW_B.pin1 | reference-connectivity-only
SW4 | 1 | /CPU/TP1 | SW_B.pin3 | reference-connectivity-only
TP1 | 1 | /CPU/TP1 | TP1.pin1 | reference-connectivity-only
U1 | 5 | /CPU/TP1 | U1.pin5 | reference-connectivity-only
U16 | 5 | /CPU/TP1 | U16.pin5 | reference-connectivity-only
C78 | 2 | /CPU/TP2 | C78.pin2 | reference-connectivity-only
SW5 | 2 | /CPU/TP2 | SW_SELECT.pin1 | reference-connectivity-only
SW5 | 2 | /CPU/TP2 | SW_SELECT.pin3 | reference-connectivity-only
TP2 | 1 | /CPU/TP2 | TP2.pin1 | reference-connectivity-only
TP29 | 1 | /CPU/TP2 | TP29.pin1 | reference-connectivity-only
U1 | 126 | /CPU/TP2 | U1.pin126 | reference-connectivity-only
U16 | 12 | /CPU/TP2 | U16.pin12 | reference-connectivity-only
C77 | 2 | /CPU/TP3 | C77.pin2 | reference-connectivity-only
SW5 | 1 | /CPU/TP3 | SW_START.pin1 | reference-connectivity-only
SW5 | 1 | /CPU/TP3 | SW_START.pin3 | reference-connectivity-only
TP3 | 1 | /CPU/TP3 | TP3.pin1 | reference-connectivity-only
U1 | 127 | /CPU/TP3 | U1.pin127 | reference-connectivity-only
U15 | 1 | /CPU/TP3 | U15.pin1 | reference-connectivity-only
C74 | 2 | /CPU/TP4 | C74.pin2 | reference-connectivity-only
SW6 | 2 | /CPU/TP4 | SW_RIGHT.pin1 | reference-connectivity-only
SW6 | 2 | /CPU/TP4 | SW_RIGHT.pin3 | reference-connectivity-only
TP4 | 1 | /CPU/TP4 | TP4.pin1 | reference-connectivity-only
U1 | 123 | /CPU/TP4 | U1.pin123 | reference-connectivity-only
C75 | 2 | /CPU/TP5 | C75.pin2 | reference-connectivity-only
SW6 | 4 | /CPU/TP5 | SW_LEFT.pin1 | reference-connectivity-only
SW6 | 4 | /CPU/TP5 | SW_LEFT.pin3 | reference-connectivity-only
TP5 | 1 | /CPU/TP5 | TP5.pin1 | reference-connectivity-only
U1 | 121 | /CPU/TP5 | U1.pin121 | reference-connectivity-only
C62 | 2 | /CPU/TP6 | C62.pin2 | reference-connectivity-only
SW6 | 1 | /CPU/TP6 | SW_UP.pin1 | reference-connectivity-only
SW6 | 1 | /CPU/TP6 | SW_UP.pin3 | reference-connectivity-only
TP6 | 1 | /CPU/TP6 | TP6.pin1 | reference-connectivity-only
U1 | 120 | /CPU/TP6 | U1.pin120 | reference-connectivity-only
U16 | 2 | /CPU/TP6 | U16.pin2 | reference-connectivity-only
C76 | 2 | /CPU/TP7 | C76.pin2 | reference-connectivity-only
SW6 | 3 | /CPU/TP7 | SW_DOWN.pin1 | reference-connectivity-only
SW6 | 3 | /CPU/TP7 | SW_DOWN.pin3 | reference-connectivity-only
TP7 | 1 | /CPU/TP7 | TP7.pin1 | reference-connectivity-only
U1 | 122 | /CPU/TP7 | U1.pin122 | reference-connectivity-only
C63 | 2 | /CPU/TP8 | C63.pin2 | reference-connectivity-only
R43 | 2 | /CPU/TP8 | R43.pin2 | reference-connectivity-only
TP27 | 1 | /CPU/TP8 | TP27.pin1 | reference-connectivity-only
TP8 | 1 | /CPU/TP8 | TP8.pin1 | reference-connectivity-only
U1 | 3 | /CPU/TP8 | U1.pin3 | reference-connectivity-only
U15 | 3 | /CPU/TP8 | U15.pin3 | reference-connectivity-only
C64 | 2 | /CPU/TP9 | C64.pin2 | reference-connectivity-only
R44 | 2 | /CPU/TP9 | R44.pin2 | reference-connectivity-only
TP28 | 1 | /CPU/TP9 | TP28.pin1 | reference-connectivity-only
TP9 | 1 | /CPU/TP9 | TP9.pin1 | reference-connectivity-only
U1 | 119 | /CPU/TP9 | U1.pin119 | reference-connectivity-only
U15 | 6 | /CPU/TP9 | U15.pin6 | reference-connectivity-only
Q8 | 1 | /CPU/VCNT5 | Q8.pin1 | reference-connectivity-only
U1 | 118 | /CPU/VCNT5 | U1.pin118 | reference-connectivity-only
C14 | 1 | /CPU/VSHD | C14.pin1 | reference-connectivity-only
P2 | 2 | /CPU/VSHD | P2.pin2 | reference-connectivity-only
P2 | 27 | /CPU/VSHD | P2.pin27 | reference-connectivity-only
P2 | 7 | /CPU/VSHD | P2.pin7 | reference-connectivity-only
R67 | 2 | /CPU/VSHD | R67.pin2 | reference-connectivity-only
U12 | 5 | /CPU/VSHD | U12.pin5 | reference-connectivity-only
U12 | 6 | /CPU/VSHD | U12.pin6 | reference-connectivity-only
P1 | 5 | /CPU/~{CS} | P1.pin5 | reference-connectivity-only
R39 | 1 | /CPU/~{CS} | R39.pin1 | reference-connectivity-only
R39 | 2 | /CPU/~{CS}_{0} | R39.pin2 | reference-connectivity-only
U1 | 34 | /CPU/~{CS}_{0} | U1.pin34 | reference-connectivity-only
U1 | 53 | /CPU/~{LB} | U1.pin53 | reference-connectivity-only
U2 | 15 | /CPU/~{LB} | U2.pin39 | reference-connectivity-only
U1 | 83 | /CPU/~{OE}_{RAM} | U1.pin83 | reference-connectivity-only
U2 | 28 | /CPU/~{OE}_{RAM} | U2.pin41 | reference-connectivity-only
P1 | 4 | /CPU/~{RD} | P1.pin4 | reference-connectivity-only
U1 | 35 | /CPU/~{RD} | U1.pin35 | reference-connectivity-only
U1 | 54 | /CPU/~{UB} | U1.pin54 | reference-connectivity-only
U2 | 14 | /CPU/~{UB} | U2.pin40 | reference-connectivity-only
U1 | 55 | /CPU/~{WE}_{RAM} | U1.pin55 | reference-connectivity-only
U2 | 11 | /CPU/~{WE}_{RAM} | U2.pin17 | reference-connectivity-only
P1 | 3 | /CPU/~{WR} | P1.pin3 | reference-connectivity-only
R38 | 1 | /CPU/~{WR} | R38.pin1 | reference-connectivity-only
R38 | 2 | /CPU/~{WR}_{0} | R38.pin2 | reference-connectivity-only
U1 | 36 | /CPU/~{WR}_{0} | U1.pin36 | reference-connectivity-only
C68 | 1 | /D1A | C68.pin1 | reference-connectivity-only
DL1 | 1 | /D1A | DL1.pin1 | reference-connectivity-only
Q9 | 3 | /D1A | Q9.pin3 | reference-connectivity-only
Q9 | 6 | /D1A | Q9.pin6 | reference-connectivity-only
DL1 | 2 | /DL1A | DL1.pin2 | reference-connectivity-only
R25 | 2 | /DL1A | R25.pin2 | reference-connectivity-only
DL2 | 2 | /DL2A | DL2.pin2 | reference-connectivity-only
Q5 | 6 | /DL2A | Q5.pin6 | reference-connectivity-only
R10 | 2 | /DL2A | R10.pin2 | reference-connectivity-only
Q10 | 3 | /EN | Q10.pin3 | reference-connectivity-only
Q10 | 5 | /EN | Q10.pin5 | reference-connectivity-only
R11 | 2 | /EN | R11.pin2 | reference-connectivity-only
R24 | 1 | /EN | R24.pin1 | reference-connectivity-only
TP24 | 1 | /EN | TP24.pin1 | reference-connectivity-only
U13 | 1 | /EN | U13.pin1 | reference-connectivity-only
U3 | 1 | /EN | U3.pin1 | reference-connectivity-only
R8 | 2 | /PG_{2V5} | R8.pin2 | reference-connectivity-only
TP30 | 1 | /PG_{2V5} | TP30.pin1 | reference-connectivity-only
U18 | 3 | /PG_{2V5} | U18.pin3 | reference-connectivity-only
U4 | 3 | /PG_{2V5} | U4.pin4 | reference-connectivity-only
U5 | 1 | /PG_{2V5} | U5.pin1 | reference-connectivity-only
U8 | 4 | /PG_{2V5} | U8.pin5 | reference-connectivity-only
R13 | 1 | /PG_{3V3} | R13.pin1 | reference-connectivity-only
TP23 | 1 | /PG_{3V3} | TP23.pin1 | reference-connectivity-only
U13 | 5 | /PG_{3V3} | U13.pin5 | reference-connectivity-only
U8 | 3 | /PG_{3V3} | U8.pin4 | reference-connectivity-only
C1 | 1 | /VFILT | C1.pin1 | reference-connectivity-only
D2 | 1 | /VFILT | D2.pin1 | reference-connectivity-only
R9 | 2 | /VFILT | R9.pin2 | reference-connectivity-only
TP26 | 1 | /VFILT | TP26.pin1 | reference-connectivity-only
U3 | 2 | /VFILT | U3.pin2 | reference-connectivity-only
Q10 | 6 | /~{MR} | Q10.pin6 | reference-connectivity-only
TP17 | 1 | /~{MR} | TP17.pin1 | reference-connectivity-only
U3 | 4 | /~{MR} | U3.pin4 | reference-connectivity-only
C30 | 2 | /~{RESET} | C30.pin2 | reference-connectivity-only
EM7 | 1 | /~{RESET} | EM7.pin1 | reference-connectivity-only
JP1 | 2 | /~{RESET} | JP1.pin2 | reference-connectivity-only
R29 | 1 | /~{RESET} | R29.pin1 | reference-connectivity-only
TP15 | 1 | /~{RESET} | TP15.pin1 | reference-connectivity-only
U5 | 5 | /~{RESET} | U5.pin5 | reference-connectivity-only
Q8 | 3 | /~{VCNT5} | Q8.pin3 | reference-connectivity-only
R7 | 2 | /~{VCNT5} | R7.pin2 | reference-connectivity-only
U11 | 3 | /~{VCNT5} | U11.pin3 | reference-connectivity-only
U12 | 3 | /~{VCNT5} | U12.pin3 | reference-connectivity-only
C26 | 2 | AGND | C26.pin2 | reference-connectivity-only
C27 | 2 | AGND | C27.pin2 | reference-connectivity-only
C31 | 2 | AGND | C31.pin2 | reference-connectivity-only
C33 | 2 | AGND | C33.pin2 | reference-connectivity-only
C36 | 2 | AGND | C36.pin2 | reference-connectivity-only
C38 | 2 | AGND | C38.pin2 | reference-connectivity-only
C54 | 2 | AGND | C54.pin2 | reference-connectivity-only
C59 | 2 | AGND | C59.pin2 | reference-connectivity-only
C9 | 2 | AGND | C9.pin2 | reference-connectivity-only
NT1 | 2 | AGND | NT1.pin2 | reference-connectivity-only
P3 | 1 | AGND | P3.pin1 | reference-connectivity-only
Q6 | 2 | AGND | Q6.pin2 | reference-connectivity-only
R19 | 2 | AGND | R19.pin2 | reference-connectivity-only
R20 | 2 | AGND | R20.pin2 | reference-connectivity-only
R45 | 2 | AGND | R45.pin2 | reference-connectivity-only
R49 | 2 | AGND | R49.pin2 | reference-connectivity-only
U6 | 4 | AGND | U6.pin4 | reference-connectivity-only
U7 | 11 | AGND | U7.pin11 | reference-connectivity-only
U9 | 2 | AGND | U9.pin2 | reference-connectivity-only
VR2 | 5 | AGND | VR2.pin1 | reference-connectivity-only
BT1 | 2 | GND | BT1.pin2 | reference-connectivity-only
C1 | 2 | GND | C1.pin2 | reference-connectivity-only
C10 | 2 | GND | C10.pin2 | reference-connectivity-only
C11 | 2 | GND | C11.pin2 | reference-connectivity-only
C12 | 2 | GND | C12.pin2 | reference-connectivity-only
C13 | 2 | GND | C13.pin2 | reference-connectivity-only
C14 | 2 | GND | C14.pin2 | reference-connectivity-only
C15 | 2 | GND | C15.pin2 | reference-connectivity-only
C16 | 2 | GND | C16.pin2 | reference-connectivity-only
C17 | 2 | GND | C17.pin2 | reference-connectivity-only
C18 | 2 | GND | C18.pin2 | reference-connectivity-only
C19 | 2 | GND | C19.pin2 | reference-connectivity-only
C2 | 2 | GND | C2.pin2 | reference-connectivity-only
C20 | 2 | GND | C20.pin2 | reference-connectivity-only
C21 | 2 | GND | C21.pin2 | reference-connectivity-only
C22 | 2 | GND | C22.pin2 | reference-connectivity-only
C23 | 2 | GND | C23.pin2 | reference-connectivity-only
C3 | 1 | GND | C3.pin1 | reference-connectivity-only
C30 | 1 | GND | C30.pin1 | reference-connectivity-only
C34 | 2 | GND | C34.pin2 | reference-connectivity-only
C37 | 2 | GND | C37.pin2 | reference-connectivity-only
C39 | 2 | GND | C39.pin2 | reference-connectivity-only
C4 | 2 | GND | C4.pin2 | reference-connectivity-only
C42 | 2 | GND | C42.pin2 | reference-connectivity-only
C43 | 2 | GND | C43.pin2 | reference-connectivity-only
C44 | 2 | GND | C44.pin2 | reference-connectivity-only
C45 | 2 | GND | C45.pin2 | reference-connectivity-only
C46 | 2 | GND | C46.pin2 | reference-connectivity-only
C47 | 2 | GND | C47.pin2 | reference-connectivity-only
C48 | 2 | GND | C48.pin2 | reference-connectivity-only
C49 | 2 | GND | C49.pin2 | reference-connectivity-only
C5 | 2 | GND | C5.pin2 | reference-connectivity-only
C50 | 2 | GND | C50.pin2 | reference-connectivity-only
C51 | 2 | GND | C51.pin2 | reference-connectivity-only
C52 | 2 | GND | C52.pin2 | reference-connectivity-only
C53 | 2 | GND | C53.pin2 | reference-connectivity-only
C57 | 2 | GND | C57.pin2 | reference-connectivity-only
C58 | 2 | GND | C58.pin2 | reference-connectivity-only
C6 | 2 | GND | C6.pin2 | reference-connectivity-only
C60 | 2 | GND | C60.pin2 | reference-connectivity-only
C61 | 2 | GND | C61.pin2 | reference-connectivity-only
C62 | 1 | GND | C62.pin1 | reference-connectivity-only
C63 | 1 | GND | C63.pin1 | reference-connectivity-only
C64 | 1 | GND | C64.pin1 | reference-connectivity-only
C68 | 2 | GND | C68.pin2 | reference-connectivity-only
C69 | 2 | GND | C69.pin2 | reference-connectivity-only
C7 | 2 | GND | C7.pin2 | reference-connectivity-only
C70 | 2 | GND | C70.pin2 | reference-connectivity-only
C71 | 2 | GND | C71.pin2 | reference-connectivity-only
C72 | 2 | GND | C72.pin2 | reference-connectivity-only
C73 | 1 | GND | C73.pin1 | reference-connectivity-only
C74 | 1 | GND | C74.pin1 | reference-connectivity-only
C75 | 1 | GND | C75.pin1 | reference-connectivity-only
C76 | 1 | GND | C76.pin1 | reference-connectivity-only
C77 | 1 | GND | C77.pin1 | reference-connectivity-only
C78 | 1 | GND | C78.pin1 | reference-connectivity-only
C79 | 1 | GND | C79.pin1 | reference-connectivity-only
C8 | 2 | GND | C8.pin2 | reference-connectivity-only
C80 | 2 | GND | C80.pin2 | reference-connectivity-only
D1 | 2 | GND | D1.pin2 | reference-connectivity-only
EM1 | 1 | GND | EM1.pin1 | reference-connectivity-only
EM2 | 3 | GND | EM2.pin3 | reference-connectivity-only
JP2 | 1 | GND | JP2.pin1 | reference-connectivity-only
NT1 | 1 | GND | NT1.pin1 | reference-connectivity-only
P1 | 32 | GND | P1.pin32 | reference-connectivity-only
P2 | 0 | GND | P2.pin41 | reference-connectivity-only
P2 | 0 | GND | P2.pin42 | reference-connectivity-only
P2 | 18 | GND | P2.pin18 | reference-connectivity-only
P2 | 35 | GND | P2.pin35 | reference-connectivity-only
P2 | 6 | GND | P2.pin6 | reference-connectivity-only
Q1 | 2 | GND | Q1.pin2 | reference-connectivity-only
Q10 | 2 | GND | Q10.pin2 | reference-connectivity-only
Q2 | 2 | GND | Q2.pin2 | reference-connectivity-only
Q2 | 5 | GND | Q2.pin5 | reference-connectivity-only
Q5 | 2 | GND | Q5.pin2 | reference-connectivity-only
Q5 | 5 | GND | Q5.pin5 | reference-connectivity-only
Q7 | 2 | GND | Q7.pin2 | reference-connectivity-only
Q7 | 5 | GND | Q7.pin5 | reference-connectivity-only
Q8 | 2 | GND | Q8.pin2 | reference-connectivity-only
Q9 | 2 | GND | Q9.pin2 | reference-connectivity-only
Q9 | 5 | GND | Q9.pin5 | reference-connectivity-only
R17 | 2 | GND | R17.pin2 | reference-connectivity-only
R24 | 2 | GND | R24.pin2 | reference-connectivity-only
R4 | 2 | GND | R4.pin2 | reference-connectivity-only
R5 | 2 | GND | R5.pin2 | reference-connectivity-only
R60 | 2 | GND | R60.pin2 | reference-connectivity-only
R63 | 2 | GND | R63.pin2 | reference-connectivity-only
R73 | 2 | GND | R73.pin2 | reference-connectivity-only
SW1 | 5 | GND |  | documented-omission
SW2 | 2 | GND | SW2.pin2 | reference-connectivity-only
SW3 | 2 | GND | SW3.pin2 | reference-connectivity-only
SW4 | 3 | GND | SW_B.pin2 | reference-connectivity-only
SW4 | 3 | GND | SW_B.pin4 | reference-connectivity-only
SW4 | 4 | GND | SW_A.pin2 | reference-connectivity-only
SW4 | 4 | GND | SW_A.pin4 | reference-connectivity-only
SW5 | 3 | GND | SW_START.pin2 | reference-connectivity-only
SW5 | 3 | GND | SW_START.pin4 | reference-connectivity-only
SW5 | 4 | GND | SW_SELECT.pin2 | reference-connectivity-only
SW5 | 4 | GND | SW_SELECT.pin4 | reference-connectivity-only
SW6 | 5 | GND | SW_UP.pin2 | reference-connectivity-only
SW6 | 5 | GND | SW_UP.pin4 | reference-connectivity-only
SW6 | 6 | GND | SW_RIGHT.pin2 | reference-connectivity-only
SW6 | 6 | GND | SW_RIGHT.pin4 | reference-connectivity-only
SW6 | 7 | GND | SW_DOWN.pin2 | reference-connectivity-only
SW6 | 7 | GND | SW_DOWN.pin4 | reference-connectivity-only
SW6 | 8 | GND | SW_LEFT.pin2 | reference-connectivity-only
SW6 | 8 | GND | SW_LEFT.pin4 | reference-connectivity-only
U1 | 102 | GND | U1.pin102 | reference-connectivity-only
U1 | 109 | GND | U1.pin109 | reference-connectivity-only
U1 | 110 | GND | U1.pin110 | reference-connectivity-only
U1 | 111 | GND | U1.pin111 | reference-connectivity-only
U1 | 112 | GND | U1.pin112 | reference-connectivity-only
U1 | 116 | GND | U1.pin116 | reference-connectivity-only
U1 | 128 | GND | U1.pin128 | reference-connectivity-only
U1 | 129 | GND |  | documented-omission
U1 | 130 | GND |  | documented-omission
U1 | 39 | GND | U1.pin39 | reference-connectivity-only
U1 | 64 | GND | U1.pin64 | reference-connectivity-only
U10 | 3 | GND | U10.pin3 | reference-connectivity-only
U11 | 2 | GND | U11.pin2 | reference-connectivity-only
U12 | 2 | GND | U12.pin2 | reference-connectivity-only
U13 | 2 | GND | U13.pin2 | reference-connectivity-only
U13 | 3 | GND | U13.pin3 | reference-connectivity-only
U13 | 8 | GND | U13.pin8 | reference-connectivity-only
U14 | 2 | GND | U14.pin2 | reference-connectivity-only
U15 | 2 | GND | U15.pin2 | reference-connectivity-only
U16 | 7 | GND | U16.pin7 | reference-connectivity-only
U17 | 3 | GND | U17.pin3 | reference-connectivity-only
U18 | 2 | GND | U18.pin2 | reference-connectivity-only
U2 | 13 | GND | U2.pin12 | reference-connectivity-only
U2 | 26 | GND | U2.pin6 | reference-connectivity-only
U2 | 27 | GND | U2.pin12 | reference-connectivity-only
U2 | 46 | GND | U2.pin34 | reference-connectivity-only
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

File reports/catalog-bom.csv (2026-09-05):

reference | manufacturer_part_number | jlcpcb | pcb_status
BT1 | B2B-PH-K-S(LF)(SN) | C131337 | supplier-imported
C1 | CL21A226KOQNNNE | C296720 | supplier-imported
C2 | CL10A106KO8NQNC | C962136 | supplier-imported
C10 | CL10B104KB8NNNC | C1591 | supplier-imported
C12 | CL10A106KO8NQNC | C962136 | supplier-imported
C21 | CL21A226KOQNNNE | C296720 | supplier-imported
C22 | CL10B105KA8NNNC | C29936 | supplier-imported
C23 | CL10A106KO8NQNC | C962136 | supplier-imported
C37 | CL10A106KO8NQNC | C962136 | supplier-imported
C42 | CL21A226KOQNNNE | C296720 | supplier-imported
C44 | CL10B105KA8NNNC | C29936 | supplier-imported
C57 | CL10A106KO8NQNC | C962136 | supplier-imported
C58 | CL21A226KOQNNNE | C296720 | supplier-imported
C59 | CL10A106KO8NQNC | C962136 | supplier-imported
C60 | CL10A106KO8NQNC | C962136 | supplier-imported
C61 | CL10C332JB8NNNC | C55395 | supplier-imported
C68 | CL10A106KO8NQNC | C962136 | supplier-imported
C72 | CL10B104KB8NNNC | C1591 | supplier-imported
C80 | CL10C332JB8NNNC | C55395 | supplier-imported
D1 | 1SS355VMTE-17 | C111695 | supplier-imported
D2 | 1SS355VMTE-17 | C111695 | supplier-imported
DL1 | 150060VS75000 | C6848499 | supplier-imported
DL2 | 150060RS75000 | C3030991 | supplier-imported
F1 | 0466002.NRHF | C3105 | supplier-imported
L1 | DFE252012P-R47M=P2 | C237552 | supplier-imported
L2 | DFE252012P-R47M=P2 | C237552 | supplier-imported
NT1 | 0603WAF0000T5E | C21189 | supplier-imported
PTC1 | 0805L075SLYR | C207023 | supplier-imported
Q1 | MMBT3904LT1G | C81464 | supplier-imported
Q3 | MMBT3906LT1G | C53444 | supplier-imported
Q5 | NDC7002N | C114648 | supplier-imported
Q9 | NDC7002N | C114648 | supplier-imported
Q10 | NDC7002N | C114648 | supplier-imported
R3 | 0603WAF5101T5E | C23186 | supplier-imported
R4 | 0603WAF3302T5E | C4216 | supplier-imported
R8 | 0603WAF1003T5E | C25803 | supplier-imported
R9 | 0603WAF1003T5E | C25803 | supplier-imported
R10 | 0603WAF2002T5E | C4184 | supplier-imported
R11 | 0603WAF1001T5E | C21190 | supplier-imported
R12 | 0603WAF1003T5E | C25803 | supplier-imported
R13 | 0603WAF1003T5E | C25803 | supplier-imported
R15 | RC0603FR-0710KL | C98220 | supplier-imported
R16 | RC0603FR-0710KL | C98220 | supplier-imported
R17 | 0603WAF1003T5E | C25803 | supplier-imported
R18 | RC0603FR-0710KL | C98220 | supplier-imported
R24 | 0603WAF1003T5E | C25803 | supplier-imported
R25 | 0603WAF3301T5E | C22978 | supplier-imported
R58 | 0603WAF5101T5E | C23186 | supplier-imported
R59 | 0603WAF8203T5E | C23252 | supplier-imported
R60 | 0603WAF9102T5E | C23265 | supplier-imported
R63 | 0603WAF1003T5E | C25803 | supplier-imported
R64 | 0603WAF2003T5E | C25811 | supplier-imported
R65 | 0603WAF1003T5E | C25803 | supplier-imported
R66 | 0603WAF1003T5E | C25803 | supplier-imported
R72 | 0603WAF5103T5E | C23192 | supplier-imported
R73 | 0603WAF9102T5E | C23265 | supplier-imported
SW1 | CSS-1210TB | C2921710 | supplier-imported
TP13 | 5015 | C2906768 | supplier-imported
TP14 | 5015 | C2906768 | supplier-imported
TP15 | 5015 | C2906768 | supplier-imported
TP16 | 5015 | C2906768 | supplier-imported
TP17 | 5015 | C2906768 | supplier-imported
TP18 | 5015 | C2906768 | supplier-imported
TP19 | 5015 | C2906768 | supplier-imported
TP20 | 5015 | C2906768 | supplier-imported
TP21 | 5015 | C2906768 | supplier-imported
TP22 | 5015 | C2906768 | supplier-imported
TP23 | 5015 | C2906768 | supplier-imported
TP24 | 5015 | C2906768 | supplier-imported
TP26 | 5015 | C2906768 | supplier-imported
TP30 | 5015 | C2906768 | supplier-imported
TP32 | 5015 | C2906768 | supplier-imported
U3 | TPS3840DL20DBVR | C2066745 | supplier-imported
U4 | TPS74525PQWDRVRQ1 | C2865628 | supplier-imported
U5 | TPS63802DLAR | C2845237 | supplier-imported
U8 | TPS74525PQWDRVRQ1 | C2865628 | supplier-imported
U10 | TPS3840DL20DBVR | C2066745 | supplier-imported
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

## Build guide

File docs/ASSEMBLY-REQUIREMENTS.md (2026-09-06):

# Required functions and population

**Superseded architecture decision, 2026-09-06:** the user explicitly selected a T113-S4 emulator-console redesign. See [S4 requirements](../s4/README.md) and [S4 connection review](../s4/CONNECTION-REVIEW.md). The controls and population observations below describe the older AGBM-02 circuit; they do not establish S4 compatibility. Its Nintendo CPU decision is historical.

Updated 2026-09-05. TI is preferred when an electrically suitable JLCPCB-imported part is available. Manufacturer preference does not establish compatibility. No required component or function may be treated as DNP to resolve a sourcing, routing, or qualification problem. Custom component footprints remain prohibited.

The current target remains the reference's buttons and LCD interface. Analog sticks and an OLED have not been selected or added. A different control or screen type requires its own electrical, mechanical, and software assessment.

## Current controls and display

The compiled placement contains all 245 expected component records and no DNP attributes. The following imported components have supplier footprints and courtyards. This is a population audit, not evidence of a working assembled console.

| Required function | Current imported part | JLCPCB | Remaining work |
|---|---|---|---|
| A, B, Start, Select, four directions | Eight Alps SKRRABE010 switches | C125046 | Underside copper keepouts, actuation fit and hardware input tests |
| L and R shoulder buttons | Two TE 1825027-5 switches | C86476 | Land/hole fit and actuation clearance |
| Power switch | CSS-1210TB | C2921710 | Verify the documented two-position adaptation and physical access |
| Stereo volume | Alps RK10J12R0A0B | C351175 | Verify gang continuity and wheel access |
| LCD connection | Amphenol 62684-402100ALF, 40-pin FFC | C2931360 | Select and qualify the actual display and cable, contact side, electrical limits and configuration passives |

The LCD connector does not substitute for a display assembly. No screen is marked DNP; the screen selection is incomplete. Reference pins that a datasheet requires to remain unconnected are NC pins, not omitted components.

## CPU decision

The [upstream design](https://github.com/MouseBiteLabs/Game-Boy-Enhance) requires the original Nintendo AGB CPU. No verified JLCPCB listing or compatible TI replacement has been established. Retaining that CPU preserves the reference architecture, but its procurement and footprint remain blocked by the JLCPCB-only import requirement. No sourcing exception is approved.

A processor such as [TI AM625](https://www.ti.com/product/AM625) has a different memory, power and display architecture. Using it would require a new board and emulator/software implementation; it is not a replacement for U1 in this schematic. Its JLCPCB import, routing feasibility under the specified via rules, and Game Boy compatibility have not been qualified. It is a research candidate only, not an approved BOM selection.

## Completion blockers remain explicit

- U1, P1 and P4 lack resolved PCB footprints. They are required components, not DNP options.
- The selected SRAM does not implement the donor BYTE option. JP3 is physically present but currently has no effect on SRAM mode. Populating this header does not restore that function; this remains a functional deviation to resolve or explicitly accept.
- Power sequencing, SRAM access timing, oscillator startup, display compatibility, audio performance and the full load budget remain unqualified. See [DATASHEET-AUDIT.md](DATASHEET-AUDIT.md).
- Routing remains disabled. Final acceptance requires completed placement, routing and copper DRC, followed by a populated prototype demonstrating startup, stable rails, memory operation, all controls, display, audio, cartridge and link functions. No present software check establishes that the board will work.

The next engineering step is to resolve the CPU procurement/architecture conflict and qualify an actual display assembly. Meanwhile, existing connection, placement and datasheet findings remain valid work in progress. No emulator redesign or removal of an interface is inferred from the TI preference.

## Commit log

2026-09-05 Initialize routing-disabled AGBM-02 adaptation with JLCPCB imports and blockers
    [AGBM-02_AA_1-1.kicad_pcb, AGBM-02_AA_1-1.kicad_sch, Audio.kicad_sch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]
2026-09-05 Add JLCPCB placement, verified pin maps, and sourcing blockers
    [catalog-bom.csv, reference-connectivity.csv]
2026-09-06 Document S4 redesign sourcing blockers and audit reference connections
    [architecture.kicad_sch, block_diagram.kicad_sch, cpu_core.kicad_sch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]
2026-09-06 Build S4 power and clock core with enforced supply connections
    [power-core-bom.csv]
2026-09-07 Connect S4 USB recovery, SD storage and all game inputs
    [power-core-bom.csv]
2026-09-07 Publish the S4 console stage as the registry entrypoint
2026-09-07 Retain Enhance audio in the S4 draft and expose volume import blockers
    [enhance-retention.csv, power-core-bom.csv]
2026-09-07 Turn the S4 draft into a console core with status LEDs and protected USB host
    [enhance-retention.csv, power-core-bom.csv]
